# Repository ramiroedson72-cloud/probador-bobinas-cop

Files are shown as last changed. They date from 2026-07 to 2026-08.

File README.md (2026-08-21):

# Probador de bobinas COP — ESP32-C3 Super Mini

Generador de disparos PWM para probar bobinas de encendido (COP). Un potenciómetro
controla la frecuencia (10–200 Hz ≈ 300–6000 RPM en motor de 4 cilindros) y el
firmware mantiene un **dwell fijo de 3 ms** recalculando el duty. La pantalla
**OLED 128×64 I2C** muestra RPM, frecuencia, dwell y el logo SISU.

Diseñado por **Ramiro** · Logo SISU en la serigrafía inferior de la placa.

## Carcasa imprimible

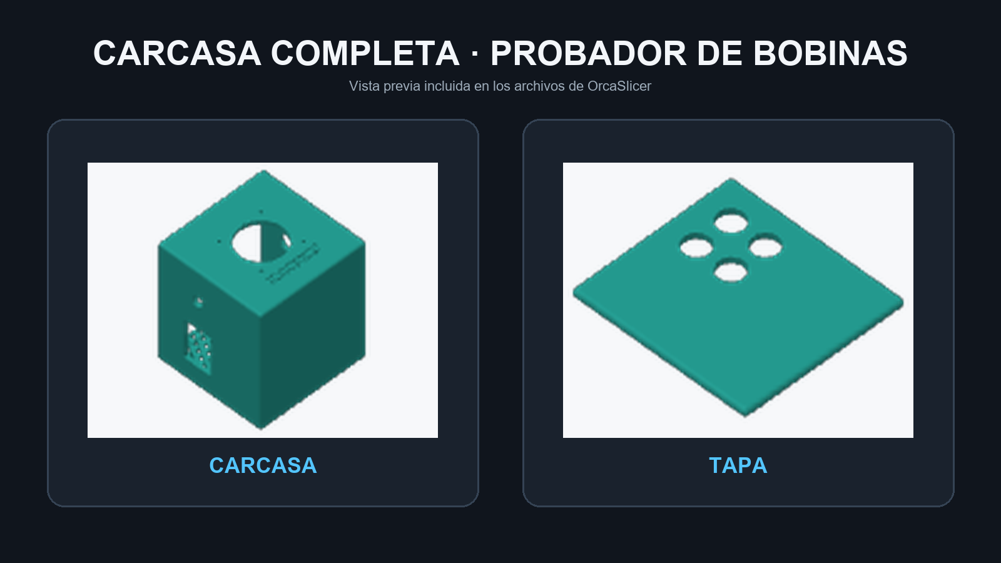
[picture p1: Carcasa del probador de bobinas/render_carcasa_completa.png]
Render de la carcasa completa y su tapa


Los archivos `carcasa.gcode` y `tapa carcasa.gcode` están listos para impresión
y fueron generados con OrcaSlicer.

## Estructura del repositorio

| Carpeta / archivo | Contenido |
|---|---|
| `Probador_Bobinas.ino` | Firmware para ESP32-C3 (Arduino) |
| `Probador_Bobinas_PCB/` | Proyecto KiCad 10 (esquemático + placa) |
| `Probador_Bobinas_PCB/PARA_FABRICAR/` | **Gerbers ZIP** — se sube tal cual a JLCPCB/PCBWay (2 capas, 1.6 mm, 1 oz) |
| `Probador_Bobinas_PCB/fabricacion/` | STEP 3D de la placa armada, esquemático PDF y BOM CSV |
| `PCB bobina Imprimir/` | PDFs 1:1 para **fabricación casera**: cobre para planchar (2), máscara UV (2), serigrafía (2) y STEP del LCD 20x4 para la carcasa |
| `Carcasa del probador de bobinas/` | G-code de la carcasa y la tapa, más su render conjunto |
| `libreria_kicad_SnapEDA/` | Librería KiCad autocontenida: símbolos, footprints y modelos 3D de todas las partes no estándar |

> Para abrir el proyecto KiCad en otra PC: registrar `libreria_kicad_SnapEDA` como
> librería "SnapEDA" (símbolos y footprints) en las tablas globales.

## La placa

- 61 × 74 × 1.6 mm, doble cara, componentes THT (pensada para soldar a mano)
- Etapa de potencia: **IGBT FGH60N60SFD** (600 V / 60 A, TO-247) con zener 15 V
  gate-emisor — reemplaza al IRLZ44N del prototipo (que avalanchaba a 55 V)
- Alimentación lógica: módulo **LM2596** 12 V → 5 V
- Clemas WAGO 236-402 (12 V y bobina), potenciómetro WH148 al borde (panel),
  header 1x4 para la pantalla OLED I2C
- Reglas de diseño: pista del colector con **2.5 mm de separación** (flyback
  ~400 V), potencia a 2 mm (10 A pulsados), señales a 0.8 mm (aptas para planchado)
- Plano de tierra cuadriculado en ambas caras; taladros M3 de esquina **H1/H2/H4
  con anillo a GND** para aterrizar la carcasa metálica (H3 solo mecánico)
- Rutas de refuerzo con alambre marcadas en la capa `Cmts.User` (retorno GND,
  colector 300 V y VCC de bobina) para la versión casera

## Cableado externo

| Conexión | Detalle |
|---|---|
| Clema J2 | Entrada 12 V (batería/fuente que aguante picos de 5–10 A) + fusible 5 A externo |
| Clema J1 | Primario de la bobina COP |
| Header J3 | OLED 128×64 I2C: 5V · GND · SDA (GPIO8) · SCL (GPIO9) |
| Cuerpo (rosca) de la bujía | GND de potencia — sin esto no hay chispa |

## Compilar y subir (Arduino IDE)

1. Instalar el core ESP32: Preferencias → URLs adicionales →
   `https://espressif.github.io/arduino-esp32/package_esp32_index.json`,
   luego Boards Manager → instalar "esp32 by Espressif Systems".
2. Instalar las librerías **Adafruit GFX** y **Adafruit SSD1306**.
3. Placa: **ESP32C3 Dev Module**, con **USB CDC On Boot: Enabled**.
4. Compilar y subir. Si no entra en modo de programación: mantener BOOT,
   pulsar RESET, soltar BOOT.

El sketch es compatible con el core ESP32 v2.x y v3.x (detecta la API de LEDC
automáticamente).

## Fabricación

**Profesional:** subir `PARA_FABRICAR/Probador_Bobinas_GERBERS.zip` a JLCPCB —
2 capas, 1.6 mm, cobre 1 oz, resto por defecto. (El PCBA no aplica: el ESP32
SuperMini y el módulo LM2596 son módulos de aftermarket que se sueldan a mano.)

**Casera (planchado + máscara UV):** PDFs en `PCB bobina Imprimir/`, impresora
láser a escala 100 % (el contorno debe medir 61 × 74 mm). Los archivos indican
en su nombre si van espejados o no. Las 7 vías se hacen con alambre pasante
soldado por ambos lados. Máscara UV: imprimir 2 acetatos por cara y encimarlos.

## Advertencias

- El primario genera picos de 300–400 V al cortar. El IGBT los soporta con
  margen, pero usar **disipador** en sesiones largas (hay espacio junto a Q1).
- No poner diodo flyback ni TVS en el primario: mata la chispa.
- Mantener los cables de alta tensión lejos del ESP32 (el EMI de la chispa
  puede resetearlo).
- Probar siempre con bujía o chispómetro conectado a la bobina.

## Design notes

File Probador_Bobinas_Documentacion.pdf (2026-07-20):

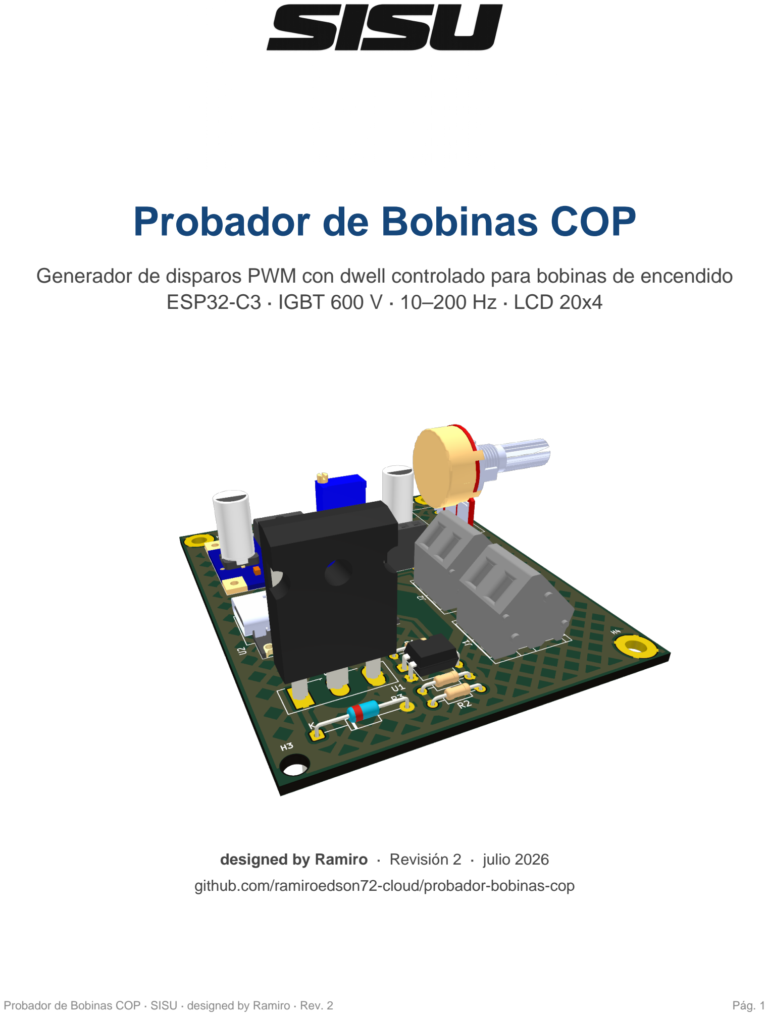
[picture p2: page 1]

Probador de Bobinas COP · SISU · designed by Ramiro · Rev. 2 | Pág. 1

# Probador de Bobinas COP

## Generador de disparos PWM con dwell controlado para bobinas de encendido ESP32-C3 · IGBT 600 V · 10–200 Hz · LCD 20x4

designed by Ramiro · Revisión 2 · julio 2026 github.com/ramiroedson72-cloud/probador-bobinas-cop

Probador de Bobinas COP · SISU · designed by Ramiro · Rev. 2 | Pág. 2

## Índice

1. Descripción general | 3
2. Especificaciones | 3
3. Firmware y funcionamiento | 4
4. La placa (PCB) | 5
5. Lista de materiales (BOM) | 7
6. Biblioteca de componentes | 7
7. Fabricación | 8
8. Puesta en marcha (primer arranque) | 8
9. Solución de problemas | 8
10. Conexión y seguridad | 10
11. Carcasa | 10
12. Historial del diseño | 10
13. Repositorio | 10
14. Código fuente comentado (Probador_Bobinas.ino) | 12

Anexo A: Esquemático completo — última página

Probador de Bobinas COP · SISU · designed by Ramiro · Rev. 2 | Pág. 3

## 1. Descripción general

El probador genera pulsos de disparo para bobinas de encendido tipo COP (Coil-On-Plug) simulando el trabajo real del motor: un potenciómetro ajusta la frecuencia de chispa entre 10 y 200 Hz (300–6000 RPM en un motor de 4 cilindros) y el firmware mantiene un dwell fijo de 3 ms recalculando el ciclo de trabajo del PWM en cada ajuste. El estado se muestra en una LCD 20x4 I2C (opcional, con autodetección) y por el monitor serial.
La cadena de disparo es: ESP32-C3 → optoacoplador PC817 → IGBT FGH60N60SFD → primario de la bobina. El optoacoplador aísla galvánicamente la lógica de 3.3 V del lado de potencia de 12 V, y el IGBT de 600 V absorbe con margen el flyback de 300–400 V que genera el primario en cada corte. Un zener de 15 V protege el gate y un módulo buck LM2596 genera los 5 V lógicos.

## 2. Especificaciones

Parámetro | Valor
Alimentación | 12 V DC (batería o fuente, picos de 5-10 A)
Frecuencia de disparo | 10 - 200 Hz (potenciómetro) = 300 - 6000 RPM en 4 cil.
Dwell | 3 ms fijos; sobre ~133 Hz lo limita el tope de duty del 40%
Corriente de primario | ~3 A con primario de 3.2 Ω (hasta ~10 A según bobina)
Flyback soportado | 300 - 400 V (IGBT de 600 V con margen)
Microcontrolador | ESP32-C3 Super Mini (USB-C)
Display | LCD 20x4 I2C (PCF8574) - opcional, autodetectado en 0x27/0x3F
Placa | 61 x 74 x 1.6 mm, 2 capas, THT
Altura máx. componentes | ~24 mm (IGBT TO-247)

Probador de Bobinas COP · SISU · designed by Ramiro · Rev. 2 | Pág. 4

## 3. Firmware y funcionamiento

El sketch (Probador_Bobinas.ino, Arduino) usa el periférico LEDC del ESP32-C3 a 14 bits de resolución, lo que permite generar con precisión todo el rango de 10 a 200 Hz. El lazo principal promedia 16 lecturas del potenciómetro, mapea el valor a frecuencia y solo reconfigura el PWM cuando el cambio es real (≥2 Hz) para evitar glitches en el tren de pulsos. El duty se recalcula como dwell x frecuencia, con tope de seguridad del 40% — por eso a más de ~133 Hz el dwell efectivo baja gradualmente de 3 ms (protege bobina e IGBT a altas RPM).

## 3.1 Asignación de pines

Pin ESP32-C3 | Función
GPIO3 (ADC) | Cursor del potenciómetro (extremos a 3V3 y GND)
GPIO4 | Salida PWM → R1 150 Ω → LED del PC817
GPIO8 | SDA de la LCD 20x4 I2C
GPIO9 | SCL de la LCD 20x4 I2C
5V | Alimentación desde el LM2596 (vía red de 5 V de la placa)

## 3.2 Interfaz

La LCD muestra frecuencia real del LEDC, RPM equivalentes (4 cilindros), dwell y duty. Si no hay LCD conectada el probador funciona igual y reporta por serial a 115200 baudios una línea cada 200 ms con el ADC crudo del potenciómetro (útil para diagnosticarlo: debe recorrer ~0 a ~4095), la frecuencia objetivo, la frecuencia real y el duty aplicado.

## 3.3 Compilación

Core ESP32 de Arduino v2.x o v3.x (el sketch detecta la API de LEDC automáticamente). Librería LiquidCrystal I2C (Frank de Brabander). Placa: ESP32C3 Dev Module con USB CDC On Boot: Enabled. Si no entra a programación: mantener BOOT, pulsar RESET, soltar BOOT.

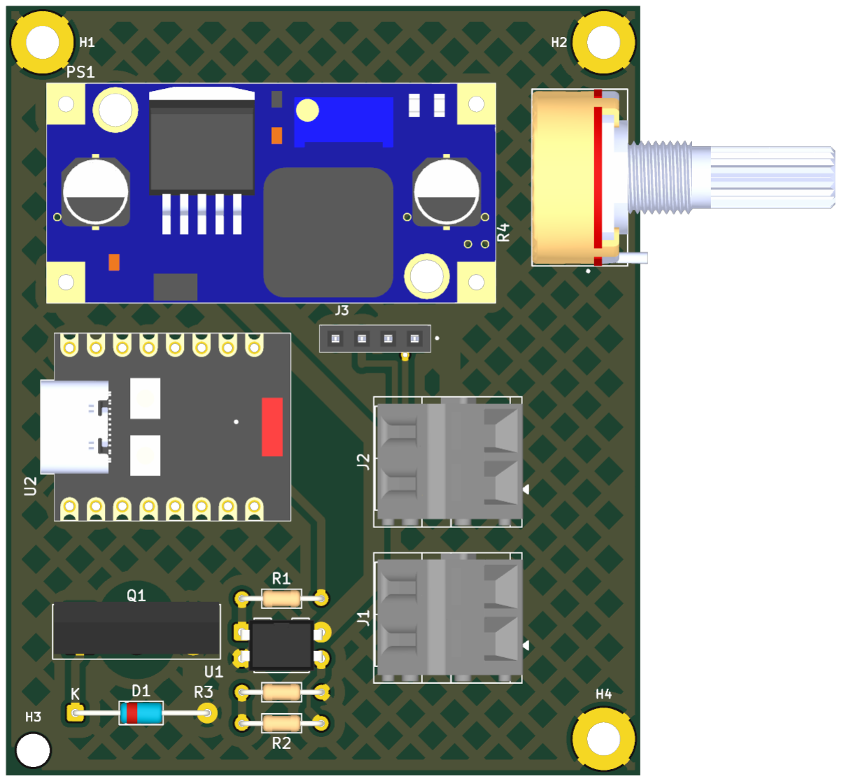
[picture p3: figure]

Probador de Bobinas COP · SISU · designed by Ramiro · Rev. 2 | Pág. 5

## 4. La placa (PCB)

Diseñada en KiCad 10, 100% THT para armado a mano. Enrutado con Freerouting más retoques manuales bajo reglas por clases de red: la pista del colector del IGBT (flyback de ~400 V) exige 2.5 mm de separación; la potencia va a 2 mm; las señales a 0.8 mm (aptas para tóner). Ambas caras llevan plano de tierra cuadriculado (1 mm / hueco 2 mm a 45°) que drena las señales parásitas, y los taladros M3 de H1, H2 y H4 tienen anillo a GND para aterrizar la carcasa metálica con los propios tornillos (H3 es solo mecánico). La cara inferior lleva el logo SISU y la leyenda designed by Ramiro. Verificación DRC final: cero violaciones.

Cara superior: LM2596 (PS1), potenciómetro al borde, ESP32-C3 (U2), clemas WAGO (J1/J2), IGBT (Q1) y etapa de disparo.

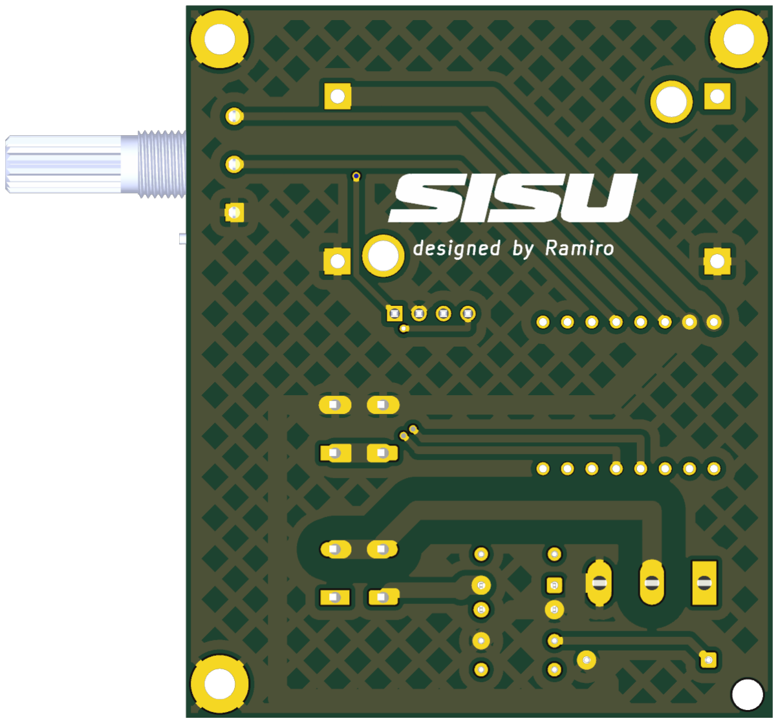
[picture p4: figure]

Probador de Bobinas COP · SISU · designed by Ramiro · Rev. 2 | Pág. 6

Cara inferior: pistas, malla GND, logo SISU. La pista ancha diagonal es el colector (alta tensión).

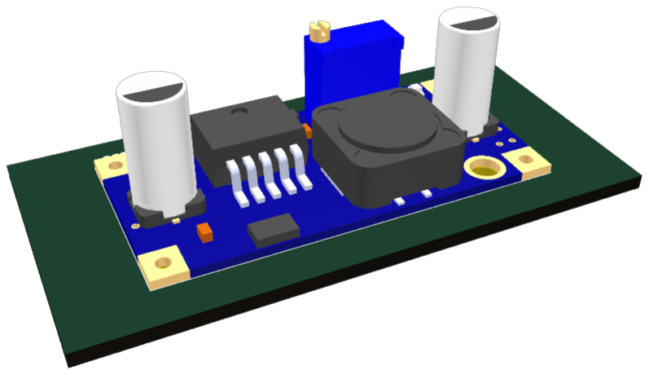
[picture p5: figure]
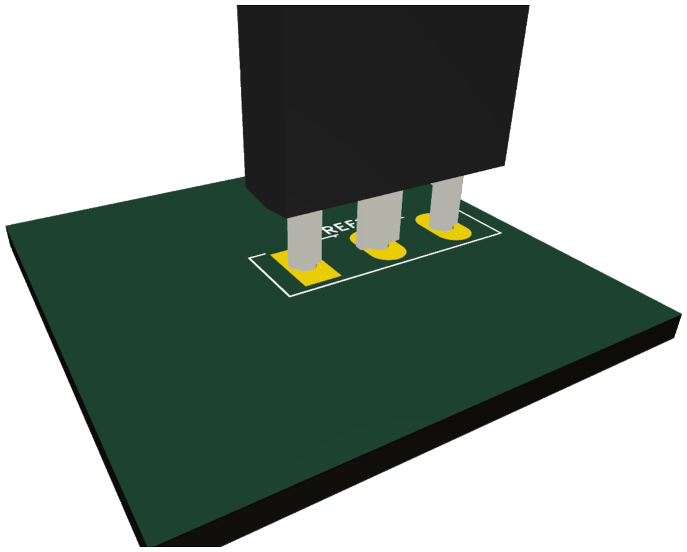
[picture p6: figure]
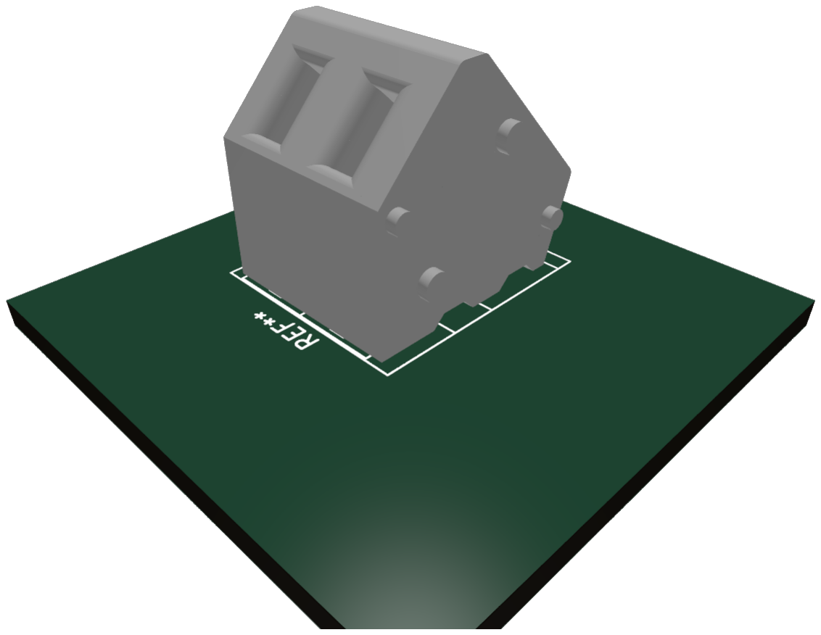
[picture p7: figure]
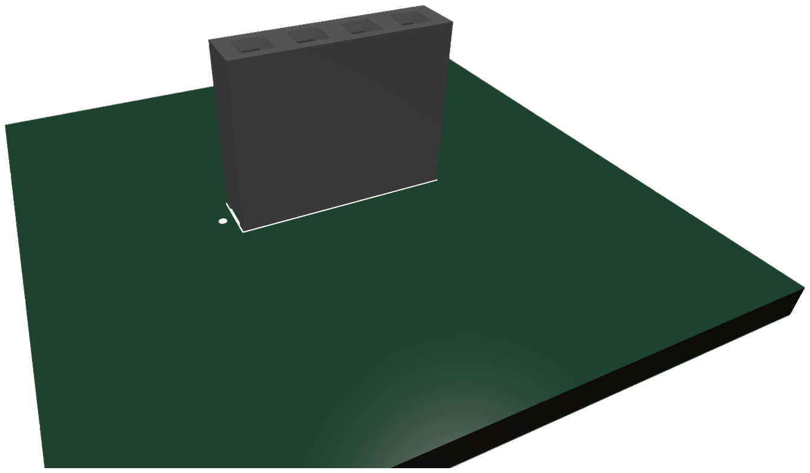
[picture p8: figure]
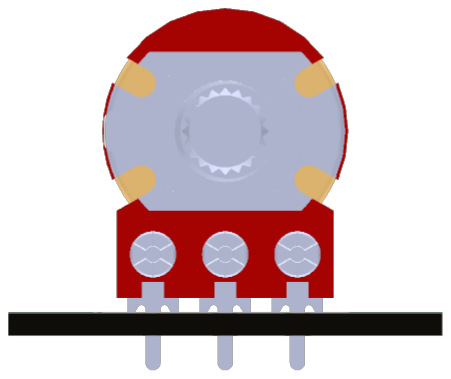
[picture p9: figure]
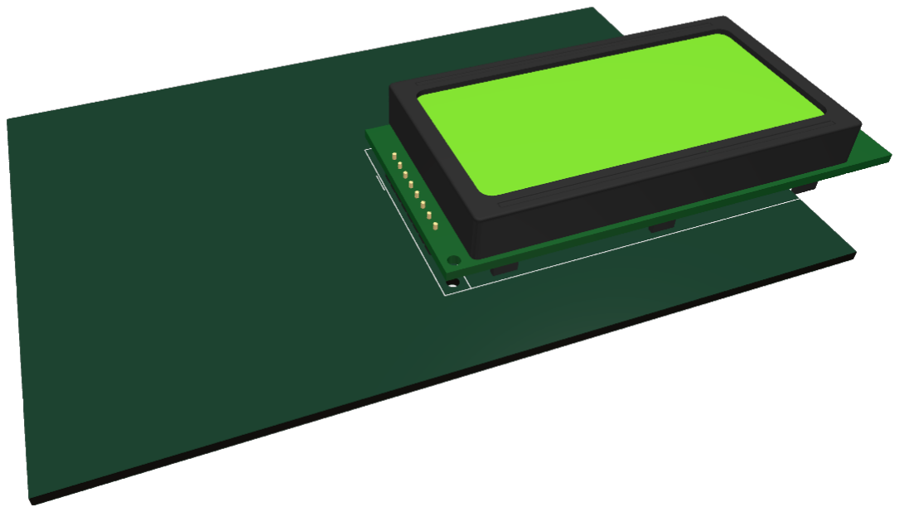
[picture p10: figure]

Probador de Bobinas COP · SISU · designed by Ramiro · Rev. 2 | Pág. 7

## 5. Lista de materiales (BOM)

Ref. | Componente | Cant.
D1 | D_Zener 15V | 1
J1,J2 | WAGO_236-402 | 2
J3 | PPTC041LFBN-RC | 1
PS1 | MC00100 | 1
Q1 | FGH60N60SFD | 1
R1 | R_150 | 1
R2 | R_100 | 1
R3 | R_560 | 1
R4 | WH148-1A-2-18T-L20 | 1
U1 | PC817 | 1
U2 | ESP32-C3_SUPERMINI_TH | 1
- | LCD 20x4 I2C (PCF8574) - externo vía J3 | 1
- | Fusible rápido 5 A con portafusible (externo) | 1
H1-H4 | Tornillos M3 (latón o acero) - H1/H2/H4 aterrizan la carcasa | 4

Valores: R1 150 Ω (serie del LED del opto), R2 100 Ω (serie de gate), R3 560 Ω (pull-down de gate), R4 potenciómetro WH148 10 kΩ, D1 zener 15 V gate-emisor.

## 6. Biblioteca de componentes

Las partes no estándar se integraron a una librería KiCad propia (símbolo + footprint + modelo 3D verificado por render). La librería viaja con el repositorio (libreria_kicad_SnapEDA) para que el proyecto abra completo en cualquier PC.

Módulo LM2596 | IGBT TO-247 | Clema WAGO 236-402
Header hembra 1x4 | Potenciómetro WH148 | LCD 20x4 (para carcasa)

Probador de Bobinas COP · SISU · designed by Ramiro · Rev. 2 | Pág. 8

## 7. Fabricación

## 7.1 Profesional (JLCPCB / PCBWay)

Subir PARA_FABRICAR/Probador_Bobinas_GERBERS.zip tal cual. Opciones: 2 capas, 1.6 mm, cobre 1 oz, resto por defecto. El PCBA no aplica: el ESP32 SuperMini y el LM2596 son módulos de aftermarket que se sueldan a mano.

## 7.2 Casera (transferencia de tóner + máscara UV)

PDFs a escala 1:1 en PCB bobina Imprimir (láser al 100%; el contorno debe medir 61 x 74 mm):

Archivo | Uso
planchar_COBRE_ABAJO_no_espejar | Cobre inferior - se imprime tal cual
planchar_COBRE_ARRIBA_ya_espejado | Cobre superior - ya viene espejado
mascaraUV_ABAJO / ARRIBA | Acetatos de máscara UV (pads en negro; 2 copias por cara encimadas)
serigrafia_ARRIBA / ABAJO | Serigrafía de componentes (arriba) y logo (abajo)

Las 7 vías se hacen con alambre pasante soldado por ambos lados. Las tres rutas de alta corriente están marcadas con línea punteada en la capa Cmts.User (retorno GND, colector 300 V y VCC de bobina): en la versión casera se refuerzan estañando un alambre de cobre desnudo (~18-20 AWG) sobre la pista. En la placa de fábrica no es necesario.

## 8. Puesta en marcha (primer arranque)

Seguir el orden: cada paso protege al siguiente.
1. Inspección visual y de continuidad: revisar con multímetro que no haya puentes entre pistas vecinas, en especial el corredor entre J3 y la clema J2 (pistas de 0.6 mm) si la placa es casera.
2. SIN el ESP32 insertado y sin bobina: conectar 12 V a J2 (con fusible de 5 A) y ajustar el trimmer del LM2596 hasta medir 5.0 V entre el pin 1 de J3 y GND. Este paso evita quemar el ESP32 si el módulo viene ajustado alto de fábrica.
3. Cortar alimentación, insertar el ESP32 (USB hacia el borde izquierdo) y reconectar. Abrir el monitor serial (115200): girar el potenciómetro y verificar que el ADC recorra ~0 a ~4095 y la frecuencia real siga a la objetivo.
4. Conectar la bobina COP en J1 y una bujía en su torre, con el cuerpo de la bujía firmemente a GND de potencia (sin este retorno no hay chispa y el flyback sube de más).
5. Arrancar en 10 Hz (potenciómetro al mínimo) y subir gradualmente. La chispa debe ser azul y constante en todo el rango.

## 9. Solución de problemas

Síntoma | Causa probable | Qué hacer
No hay chispa | Bujía sin retorno a GND / bobina mal conectada / fusible abierto | Verificar cuerpo de bujía a GND de potencia, continuidad de J1 y fusible
Chispa débil o intermitente | Dwell insuficiente a alta frecuencia / 12 V caídos | Probar a baja frecuencia; alimentar con batería o fuente de 5-10 A
El ESP32 se reinicia al chispear | EMI del secundario / cables de AT junto a la lógica | Alejar bobina y cables de bujía de la placa; verificar malla GND y carcasa aterrizada
LCD no enciende o basura | Dirección I2C distinta / contraste / cables SDA-SCL cruzados | El firmware busca 0x27 y 0x3F; ajustar trimmer del backpack; revisar J3

Probador de Bobinas COP · SISU · designed by Ramiro · Rev. 2 | Pág. 9
Síntoma | Causa probable | Qué hacer
IGBT muy caliente | Sesión larga a alta frecuencia sin disipador | Atornillar disipador al TO-247 (hay espacio junto a Q1); pausar entre pruebas
ADC no llega a 0 o a 4095 | Potenciómetro mal cableado o dañado | Ver monitor serial; revisar soldaduras de R4 (extremos a 3V3/GND, cursor a GPIO3)

Probador de Bobinas COP · SISU · designed by Ramiro · Rev. 2 | Pág. 10

## 10. Conexión y seguridad

Punto | Conexión
Clema J2 | Entrada 12 V (con fusible externo de 5 A rápido)
Clema J1 | Primario de la bobina COP
Header J3 | LCD 20x4 I2C: 5V - GND - SDA (GPIO8) - SCL (GPIO9)
Bujía | El cuerpo (rosca) va a GND de potencia
Potenciómetro | Frecuencia de disparo (10-200 Hz)
USB-C del ESP32 | Reprogramación y monitor serial

Seguridad: el secundario de una bobina COP supera los 30 kV — nunca tocar la bujía ni su torre con el equipo energizado. Probar siempre con bujía o chispómetro conectado. No agregar diodo flyback ni TVS al primario (mata la chispa). Personas con marcapasos deben mantener distancia. Trabajar en área ventilada y sin combustibles cerca.

## 11. Carcasa

Placa de 61 x 74 mm; taladros M3 en H1 (93.5, 41.5), H2 (147.5, 41.5), H3 (92.6, 109.6) y H4 (147.5, 108.5) en coordenadas del proyecto. Altura interior mínima 35 mm. El eje del potenciómetro sale ~20 mm por el borde derecho (atraviesa el panel); las clemas miran al mismo lado; el USB-C queda a la izquierda (prever ranura). Si la carcasa es metálica, los tornillos de H1/H2/H4 la aterrizan al plano GND (usar rondana dentada en al menos uno). El LCD 20x4 (98 x 60 mm, ventana 76 x 25 mm, taladros 93 x 55 mm) requiere ~25 mm de profundidad con su backpack I2C. Modelos 3D en el repositorio: Probador_Bobinas_3D.step y LCD_20x4_NHD-0420H1Z.step.

## 12. Historial del diseño

Versión | Descripción | Estado
v1 - protoboard | IRLZ44N (MOSFET 55 V): el flyback se disipaba en avalancha dentro del transistor. A alta frecuencia la disipación lo quemó; se limitó el firmware a 60 Hz y dwell 2 ms. | Superada
v2 - PCB (esta) | IGBT FGH60N60SFD de 600 V: absorbe el flyback con margen. Rango completo de 10-200 Hz y dwell de 3 ms restaurados. PCB con reglas de alta tensión, malla GND y carcasa aterrizable. | Actual

## 13. Repositorio

Proyecto completo (público): github.com/ramiroedson72-cloud/probador-bobinas-cop — firmware Arduino, proyecto KiCad, gerbers, PDFs de fabricación casera, librería de componentes autocontenida,
STEP 3D, esquemático PDF, BOM y esta documentación.

Escanea para abrir el repositorio en GitHub

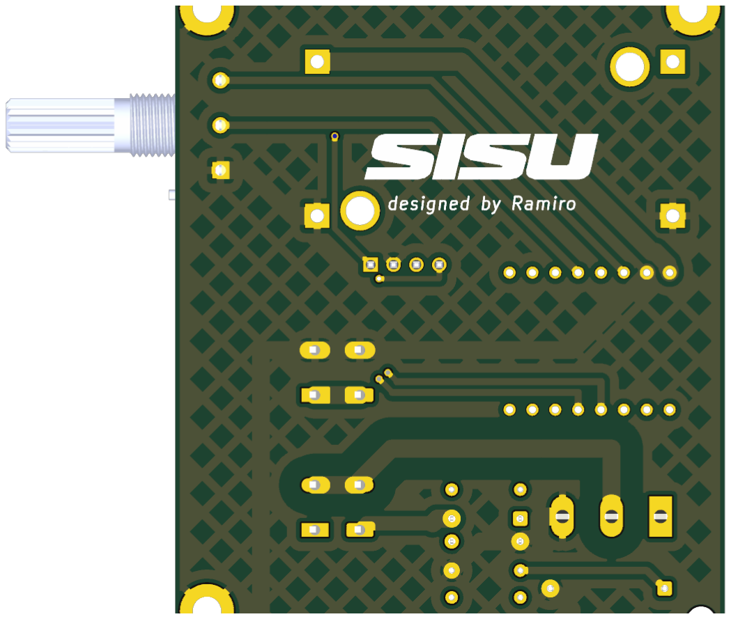
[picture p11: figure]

Probador de Bobinas COP · SISU · designed by Ramiro · Rev. 2 | Pág. 11

Detalle de la cara inferior: logo SISU y designed by Ramiro en serigrafía.

Probador de Bobinas COP · SISU · designed by Ramiro · Rev. 2 | Pág. 12

## 14. Código fuente comentado (Probador_Bobinas.ino)

El firmware cabe en un solo sketch de ~165 líneas. Su estructura:

Bloque | Qué hace
Configuración | Pines (pot GPIO3, PWM GPIO4, I2C 8/9) y constantes: FREQ 10-200 Hz, DWELL 3 ms, tope de duty 40%, LEDC a 14 bits (necesarios para que las frecuencias bajas no fallen en silencio).
detectarLcd() | Busca el backpack PCF8574 en 0x27 y 0x3F; si no aparece, el equipo opera solo con el monitor serial.
aplicarPwm() / freqReal() | Capa de compatibilidad entre el core ESP32 v2.x (API de canales) y v3.x (API por pin), con verificación de que el LEDC aceptó la frecuencia.
dutyParaDwell() | Convierte el dwell fijo en duty proporcional a la frecuencia (duty = dwell x f), recortado al 40% de seguridad.
setup() | Serial, I2C + LCD, ADC a 12 bits y arranque del PWM en 10 Hz; si el LEDC falla, se detiene con mensaje de error.
loop() | Promedia 16 lecturas del pot, mapea a frecuencia y solo reconfigura el LEDC con cambios reales (>=2 Hz) para no glitchear el tren de pulsos; refresca LCD/serial cada 200 ms con frecuencia real, RPM, dwell y duty.

## 14.1 Listado completo

/*
* Probador de bobinas de encendido COP
* ESP32-C3 Super Mini + PC817 + IGBT FGH60N60SFD (PCB v2)
*
* El potenciometro controla la frecuencia de disparo (10-200 Hz). * El dwell (tiempo de carga de la bobina) se mantiene fijo en 3 ms * recalculando el duty en cada cambio, con tope de seguridad del 40% * (a mas de ~133 Hz el tope reduce el dwell gradualmente).
*
* Conexiones (segun PCB v2):
* | GPIO3 <- cursor del potenciometro WH148 (extremos a 3V3 y GND)
* | GPIO4 -> R1 150R -> pin 1 PC817 (pin 2 a GND logico)
* | GPIO8 -> SDA de la LCD 20x4 (backpack PCF8574, alimentada a 5V)
* | GPIO9 -> SCL de la LCD
*
* Compatible con el core ESP32 de Arduino v2.x y v3.x.
*/

#include <Wire.h>

#include <LiquidCrystal_I2C.h>

// ---------- Configuracion ----------
const int | PIN_POT | = 3; | // entrada ADC del potenciometro
const int | PIN_PWM | = 4; | // salida hacia el opto/MOSFET
const int | PIN_SDA | = 8;
const int | PIN_SCL | = 9;
const int | FREQ_MIN = 10; | // Hz (= 300 RPM en motor 4 cil.)
// Con el IGBT FGH60N60SFD (600 V) el flyback de la bobina ya no se disipa // en avalancha: el rango completo es seguro. (Con el IRLZ44N del prototipo // v1 habia que limitar a 60 Hz porque el MOSFET clampeaba a 55 V y ardia.)
const int | FREQ_MAX = 200; | // Hz (= 6000 RPM en motor 4 cil.)
// 3 ms: dwell tipico de bobina COP (primario 3.2 ohms -> ~3 A de pico). const float DWELL_MS = 3.0; // tiempo de carga de la bobina
const float DUTY_MAX = 0.40; // tope de seguridad de duty (40%)

// 14 bits: con el reloj de 80 MHz el LEDC acepta de 4.8 Hz a 4.8 kHz, // asi todo el rango 10-200 Hz es valido. Con 12 bits el minimo era // ~19 Hz y las frecuencias bajas fallaban en silencio.
const int RES_BITS = 14;
const uint32_t DUTY_FULL = (1UL << RES_BITS) - 1;

#if !defined(ESP_ARDUINO_VERSION_MAJOR) || ESP_ARDUINO_VERSION_MAJOR < 3

#define CORE_V2 | // API antigua de LEDC (canales)

const int PWM_CHANNEL = 0;
#endif

LiquidCrystal_I2C *lcd = nullptr;
bool hayLcd = false;
int freqActual = 0; | // frecuencia aplicada al LEDC
uint32_t lastLcd = 0;

// Busca la LCD en las dos direcciones tipicas del backpack PCF8574

Probador de Bobinas COP · SISU · designed by Ramiro · Rev. 2 | Pág. 13

uint8_t detectarLcd() {
const uint8_t dirs[] = {0x27, 0x3F};
for (uint8_t d : dirs) {
Wire.beginTransmission(d);

if (Wire.endTransmission() == 0) return d; }
return 0;
}

// Devuelve la frecuencia que el LEDC esta generando de verdad uint32_t freqReal() {
#ifdef CORE_V2

return ledcReadFreq(PWM_CHANNEL);
#else

return ledcReadFreq(PIN_PWM);
#endif

}

// Reconfigura el LEDC. Devuelve false si el driver rechazo la frecuencia. bool aplicarPwm(int freq, uint32_t duty) {
#ifdef CORE_V2

bool ok = ledcChangeFrequency(PWM_CHANNEL, freq, RES_BITS) != 0; ledcWrite(PWM_CHANNEL, duty);
#else

bool ok = ledcChangeFrequency(PIN_PWM, freq, RES_BITS) != 0; ledcWrite(PIN_PWM, duty);
#endif

return ok;
}

uint32_t dutyParaDwell(int freq) {
float dutyFrac = DWELL_MS * freq / 1000.0f; if (dutyFrac > DUTY_MAX) dutyFrac = DUTY_MAX; return dutyFrac * DUTY_FULL;
}

void setup() {
Serial.begin(115200);

Wire.begin(PIN_SDA, PIN_SCL);
uint8_t dir = detectarLcd();
if (dir != 0) {
lcd = new LiquidCrystal_I2C(dir, 20, 4); lcd->init();
lcd->backlight();
lcd->setCursor(0, 0);
lcd->print("Probador de bobinas");
hayLcd = true;
Serial.printf("LCD encontrada en 0x%02X\n", dir);
} else {
Serial.println("LCD no detectada, sigo solo con Serial"); }

analogReadResolution(12);

#ifdef CORE_V2

ledcSetup(PWM_CHANNEL, FREQ_MIN, RES_BITS); ledcAttachPin(PIN_PWM, PWM_CHANNEL);
bool pwmOk = true;
#else

bool pwmOk = ledcAttach(PIN_PWM, FREQ_MIN, RES_BITS);
#endif

if (!pwmOk) {
Serial.println("ERROR: fallo la configuracion del PWM (LEDC)");
if (hayLcd) { lcd->setCursor(0, 1); lcd->print("ERROR config PWM!"); } while (true) delay(1000); // no tiene caso seguir
}

freqActual = FREQ_MIN;
aplicarPwm(FREQ_MIN, dutyParaDwell(FREQ_MIN));
}

void loop() {
// Promedio de 16 lecturas para estabilizar el pot
long suma = 0;
for (int i = 0; i < 16; i++) suma += analogRead(PIN_POT); int adc = suma / 16;

int freq = map(adc, 0, 4095, FREQ_MIN, FREQ_MAX);

// Solo reconfigurar el LEDC cuando el cambio es real (>= 2 Hz). // Reconfigurar en cada vuelta del loop reinicia el temporizador // antes de completar un periodo y el PWM sale glitcheado.
if (abs(freq - freqActual) >= 2) {
freqActual = freq;
if (!aplicarPwm(freqActual, dutyParaDwell(freqActual))) { Serial.printf("ERROR: LEDC rechazo %d Hz\n", freqActual); }
}

// Refresco de pantalla y serial cada 200 ms
if (millis() - lastLcd >= 200) {

Probador de Bobinas COP · SISU · designed by Ramiro · Rev. 2 | Pág. 14

lastLcd = millis();
int rpm = freqActual * 30; // motor 4 tiempos, 4 cilindros
int dutyPct = int(100.0f * dutyParaDwell(freqActual) / DUTY_FULL);

if (hayLcd) {
char linea[21];
snprintf(linea, sizeof(linea), "Frec: %3d Hz | ", (int)freqReal());
lcd->setCursor(0, 1); lcd->print(linea);
snprintf(linea, sizeof(linea), "RPM (4cil): %5d ", rpm); lcd->setCursor(0, 2); lcd->print(linea);
snprintf(linea, sizeof(linea), "Dwell:%.1fms D:%2d%% ", DWELL_MS, dutyPct); lcd->setCursor(0, 3); lcd->print(linea);
}
// adc crudo para diagnosticar el pot: debe ir de ~0 a ~4095 al girarlo Serial.printf("adc=%4d f_obj=%3d Hz f_real=%3u Hz duty=%d%%\n", adc, freqActual, freqReal(), dutyPct); }
}

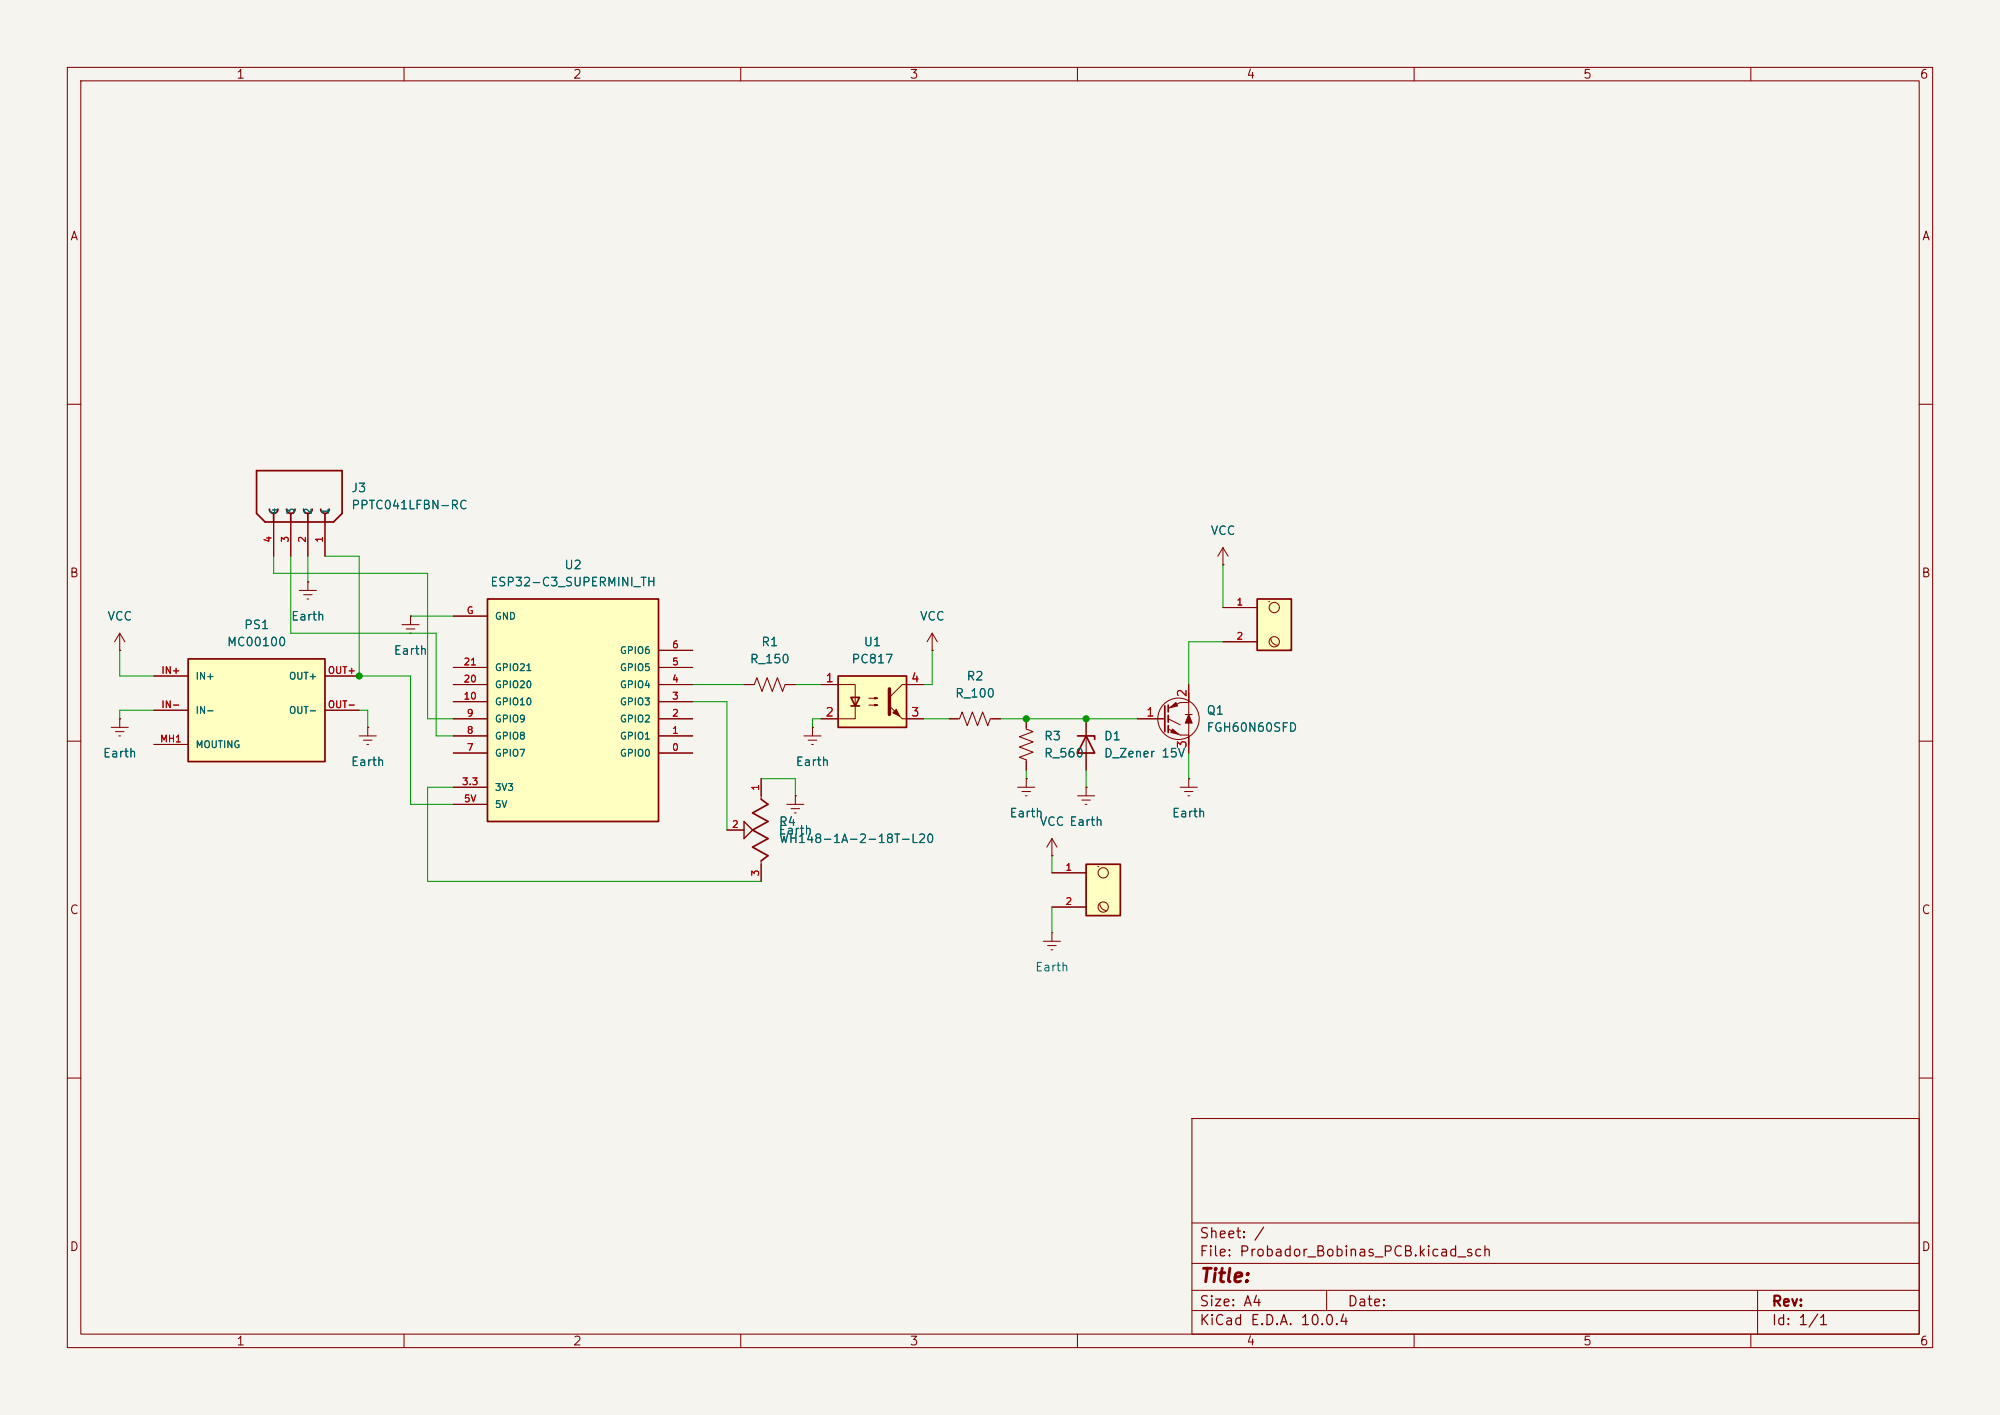
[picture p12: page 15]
D Date:; KiCad E.D.A. 10.0.4; Size: A4; Rev:; Title:; File: Probador_Bobinas_PCB.kicad_sch; Sheet: /; GPIO0; 0 GPIO1; 1 GPIO2; 2 GPIO3; GPIO4; 4 GPIO5; GPIO6; 6 GPIO7 7; GPIO8 8; GPIO9 9; GPIO10 10; GPIO20 20; GPIO21 21; GND G; ESP32-C3_SUPERMINI_TH; 4 J3PPTC041LFBN-RC; Earth; VCC; FGH60N60SFD; Earth R3R_560; Earth R2 R_100; MOUTING MH1; OUT+ OUT+; OUT- OUT- PS1 MC00100; D1D_Zener 15V; Earth PS1 MC00100; OUT- OUT-; J3 1PPTC041LFBN-RC; 2 Earth; VCC Q1

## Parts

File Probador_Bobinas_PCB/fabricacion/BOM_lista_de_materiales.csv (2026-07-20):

Referencia | Valor | Footprint | Cantidad
D1 | D_Zener 15V | Diode_THT:D_DO-35_SOD27_P12.70mm_Horizontal | 1
J1,J2 | WAGO_236-402 | SnapEDA:TerminalBlock_WAGO_236-402_1x02_P5.00mm_45Degree | 2
J3 | PPTC041LFBN-RC | SnapEDA:SULLINS_PPTC041LFBN-RC | 1
PS1 | MC00100 | SnapEDA:CONV_MC00100 | 1
Q1 | FGH60N60SFD | SnapEDA:TO-247-3_Vertical | 1
R1 | R_150 | Resistor_THT:R_Axial_DIN0204_L3.6mm_D1.6mm_P7.62mm_Horizontal | 1
R2 | R_100 | Resistor_THT:R_Axial_DIN0204_L3.6mm_D1.6mm_P7.62mm_Horizontal | 1
R3 | R_560 | Resistor_THT:R_Axial_DIN0204_L3.6mm_D1.6mm_P7.62mm_Horizontal | 1
R4 | WH148-1A-2-18T-L20 | SnapEDA:TRIM_WH148-1A-2-18T-L20 | 1
U1 | PC817 | Package_DIP:DIP-4_W7.62mm | 1
U2 | ESP32-C3_SUPERMINI_TH | SnapEDA:MODULE_ESP32-C3_SUPERMINI_TH | 1

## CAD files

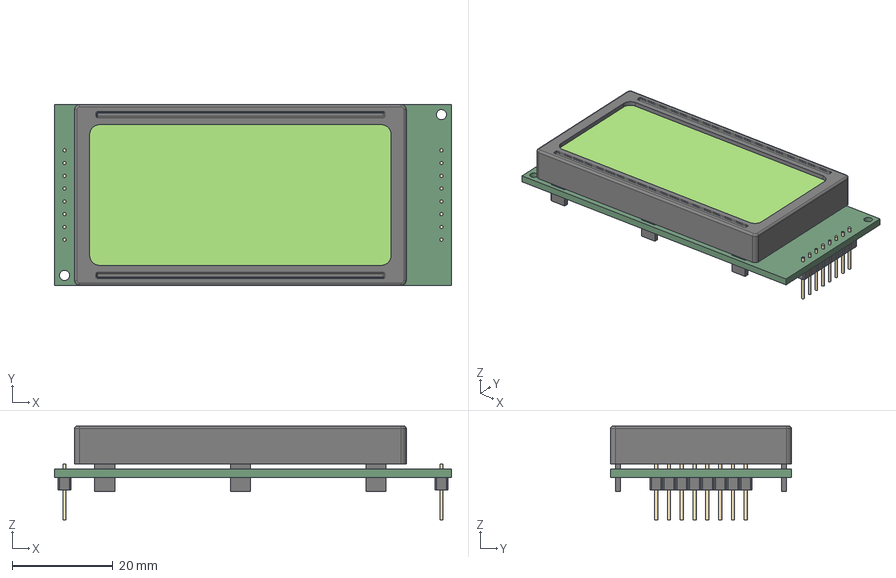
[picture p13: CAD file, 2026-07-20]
PCB bobina Imprimir/LCD_20x4_NHD-0420H1Z.step
79.0 x 36.0 x 18.7 mm

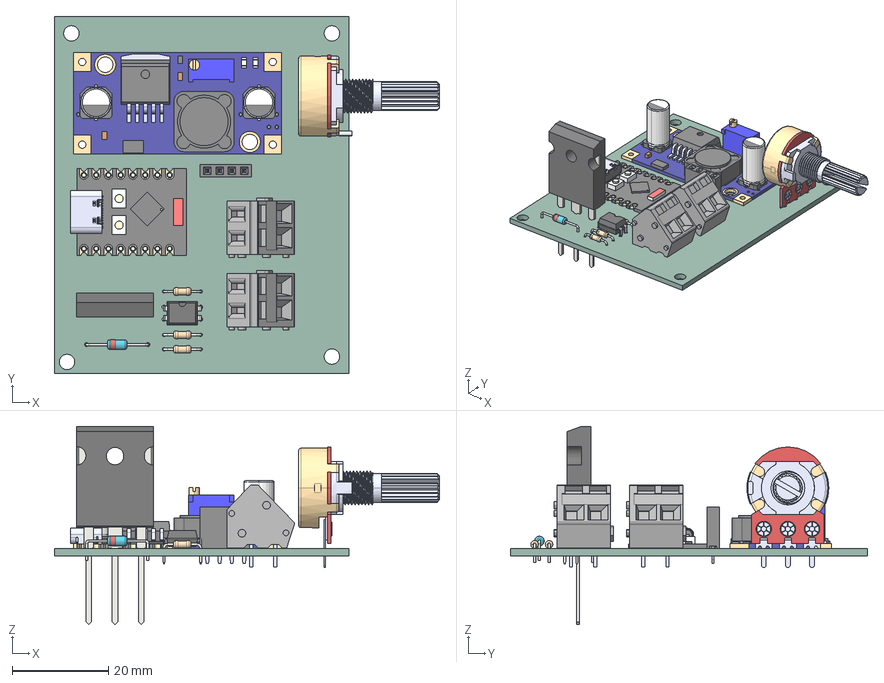
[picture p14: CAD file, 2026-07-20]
Probador_Bobinas_PCB/fabricacion/Probador_Bobinas_3D.step
79.8 x 74.0 x 41.1 mm
MC00100
3296W-1-104
DR125-331-R
LM2596DSADJG
EEE1HA470XAP x 2
R_Axial_DIN0204_L36mm_D16mm_P762mm_Horizontal x 3
Board c3mini
USB C
components (other)^ESP32-C3 SuperMini
PPTC041LFBN-RC
DIP-4_W7.62mm
WH148-1A-2
D_DO-35_SOD27_P12.70mm_Horizontal
TO-247-3_Vertical
Probador_Bobinas_PCB_PCB

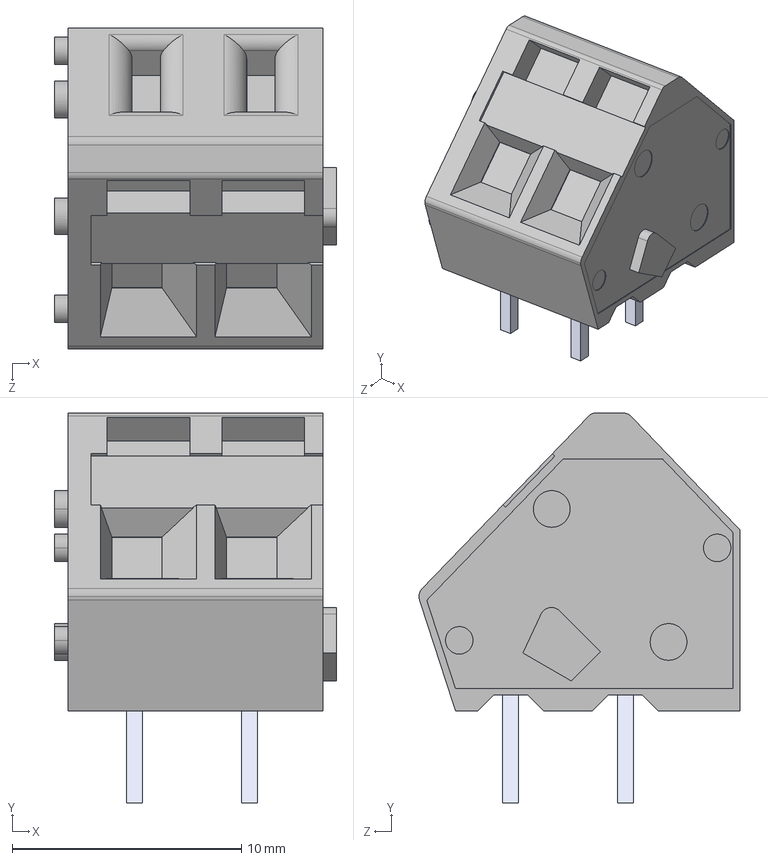
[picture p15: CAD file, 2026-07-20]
libreria_kicad_SnapEDA/3dmodels/WAGO_236-402.step
12.3 x 17.0 x 14.0 mm

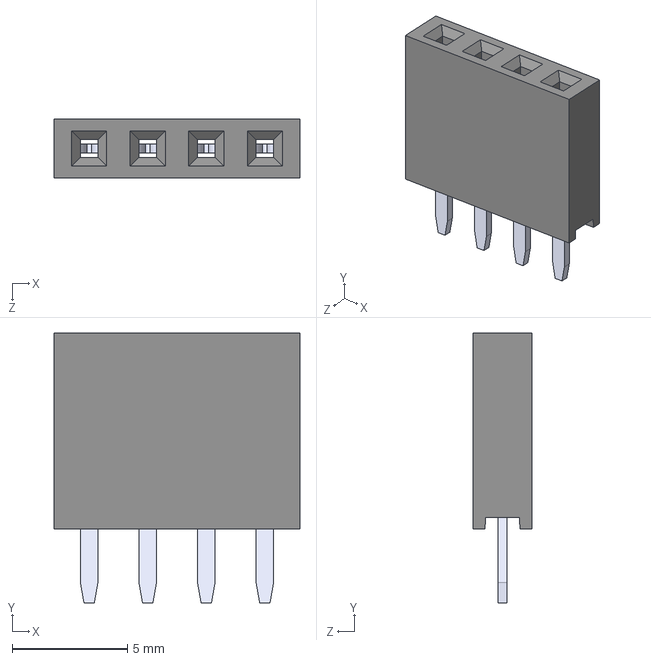
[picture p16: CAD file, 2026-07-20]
libreria_kicad_SnapEDA/3dmodels/PPTC041LFBN-RC.step
10.7 x 11.7 x 2.54 mm

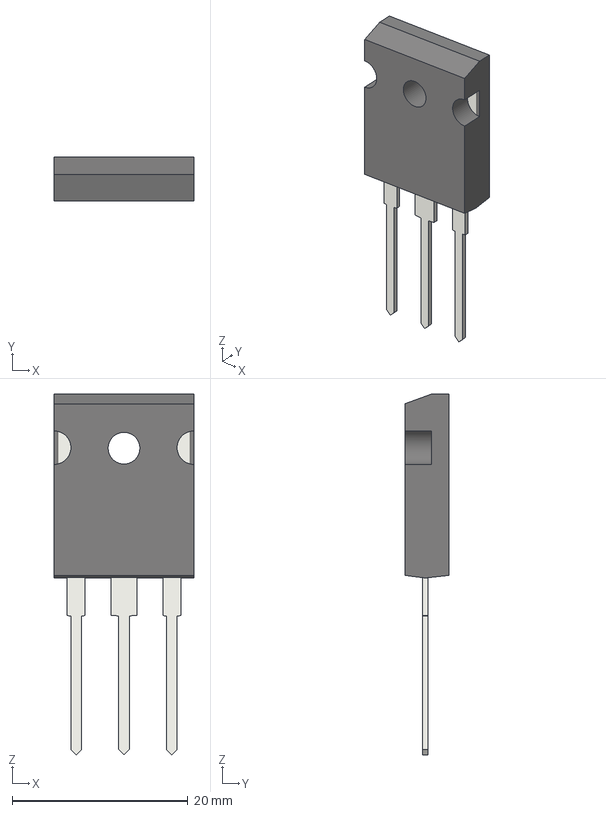
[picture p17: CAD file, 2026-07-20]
libreria_kicad_SnapEDA/3dmodels/TO-247-3_Vertical.step
15.9 x 5.03 x 41.1 mm

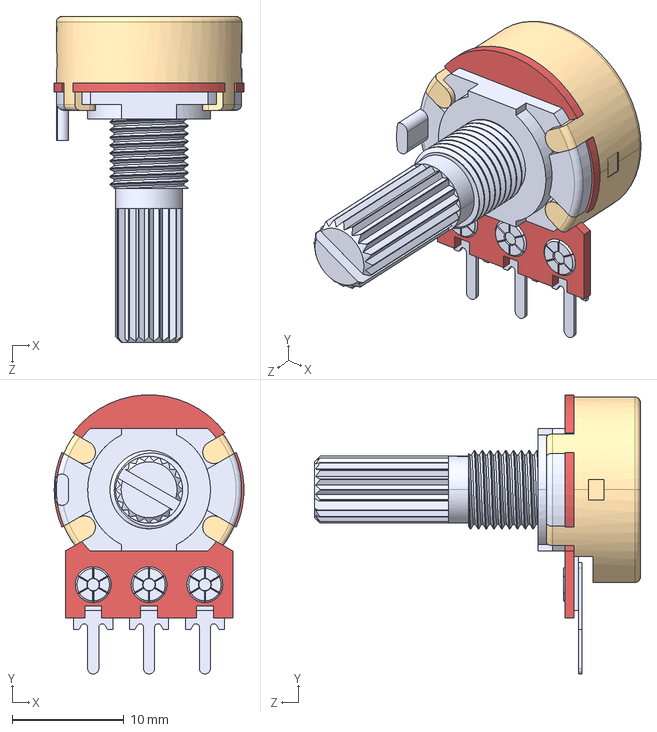
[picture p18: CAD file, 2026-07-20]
libreria_kicad_SnapEDA/3dmodels/WH148-1A-2-18T-L20.step
17.0 x 25.0 x 29.2 mm

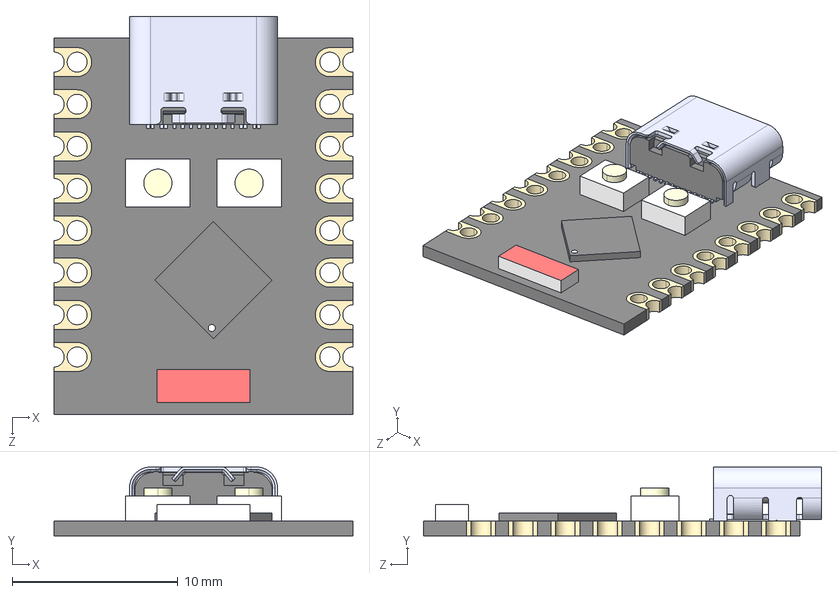
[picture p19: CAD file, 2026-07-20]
libreria_kicad_SnapEDA/3dmodels/ESP32-C3_SUPERMINI_TH.step
18.0 x 4.16 x 24.0 mm
Board c3mini
USB C
components (other)^ESP32-C3 SuperMini

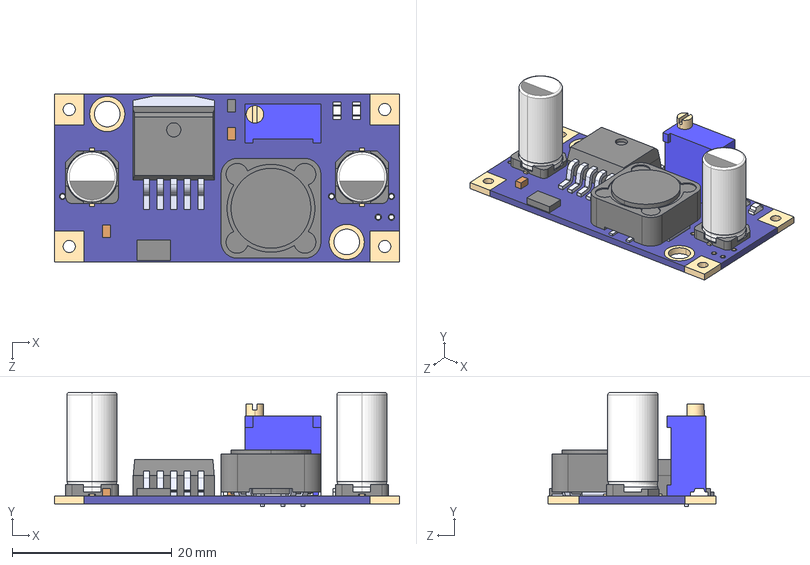
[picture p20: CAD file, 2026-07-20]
libreria_kicad_SnapEDA/3dmodels/MC00100.step
43.2 x 14.3 x 21.1 mm
MC00100
3296W-1-104
DR125-331-R
LM2596DSADJG
EEE1HA470XAP x 2

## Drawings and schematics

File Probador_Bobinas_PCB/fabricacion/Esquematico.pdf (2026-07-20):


Size: A4 | Rev:
KiCad E.D.A. 10.0.4 | Id: 1/1

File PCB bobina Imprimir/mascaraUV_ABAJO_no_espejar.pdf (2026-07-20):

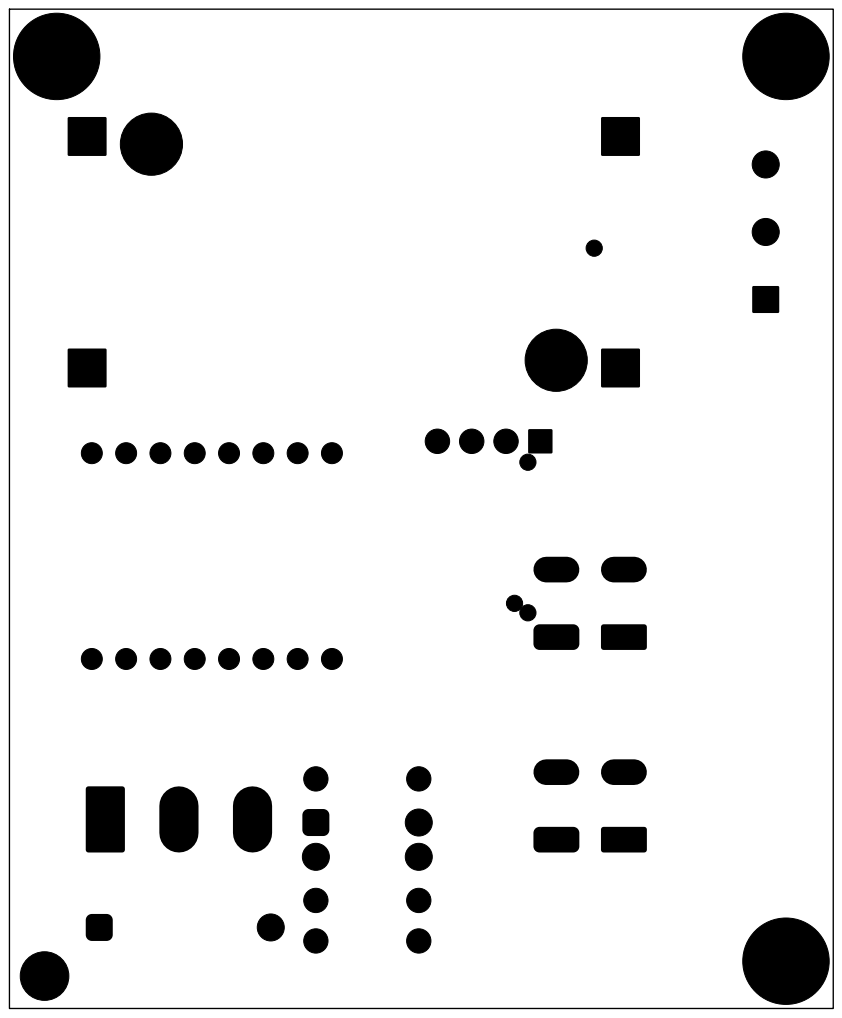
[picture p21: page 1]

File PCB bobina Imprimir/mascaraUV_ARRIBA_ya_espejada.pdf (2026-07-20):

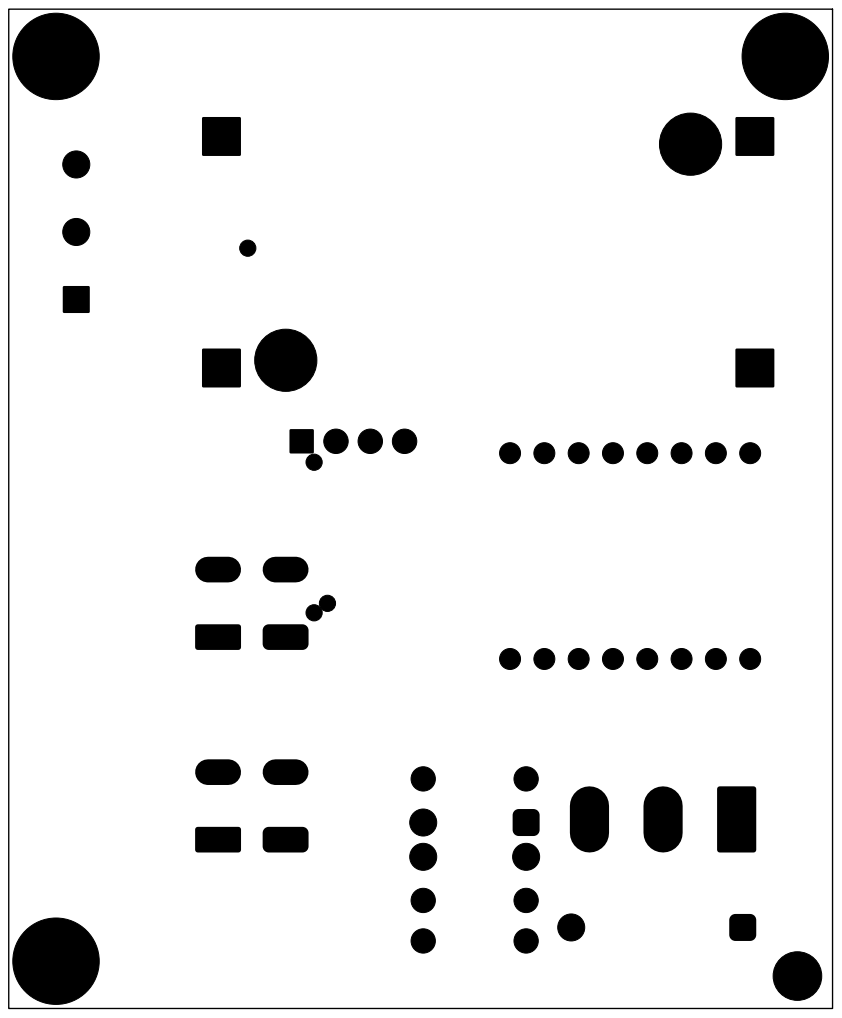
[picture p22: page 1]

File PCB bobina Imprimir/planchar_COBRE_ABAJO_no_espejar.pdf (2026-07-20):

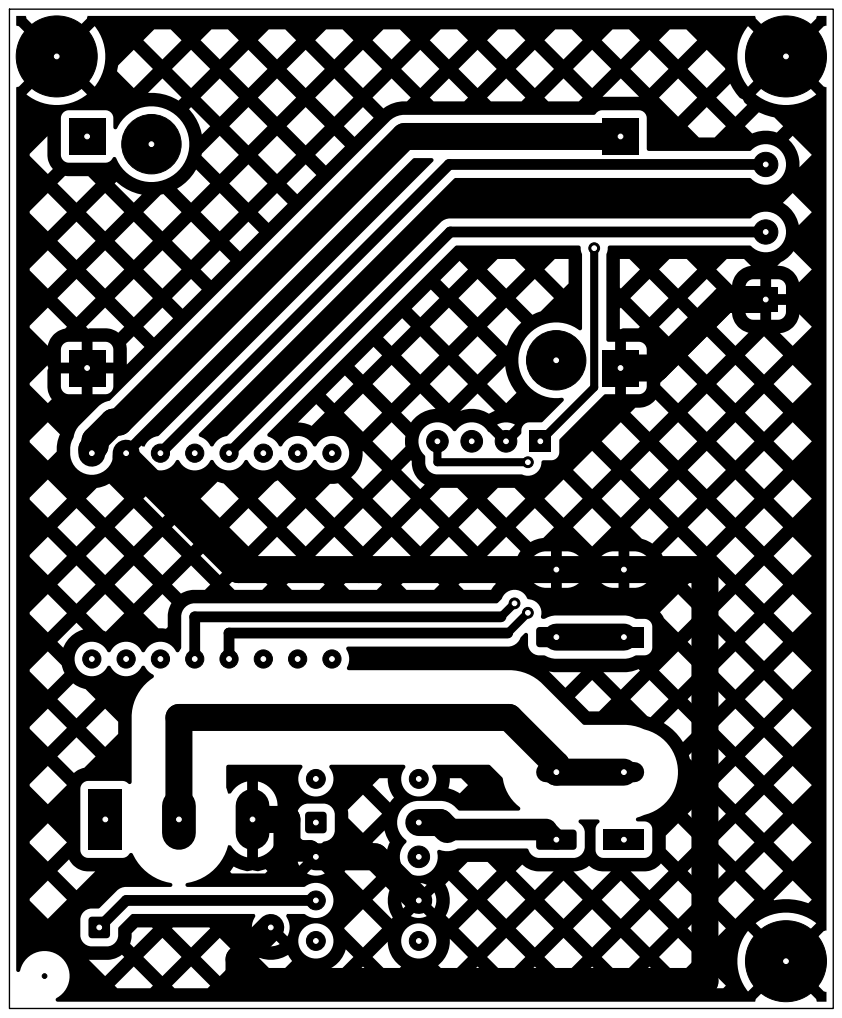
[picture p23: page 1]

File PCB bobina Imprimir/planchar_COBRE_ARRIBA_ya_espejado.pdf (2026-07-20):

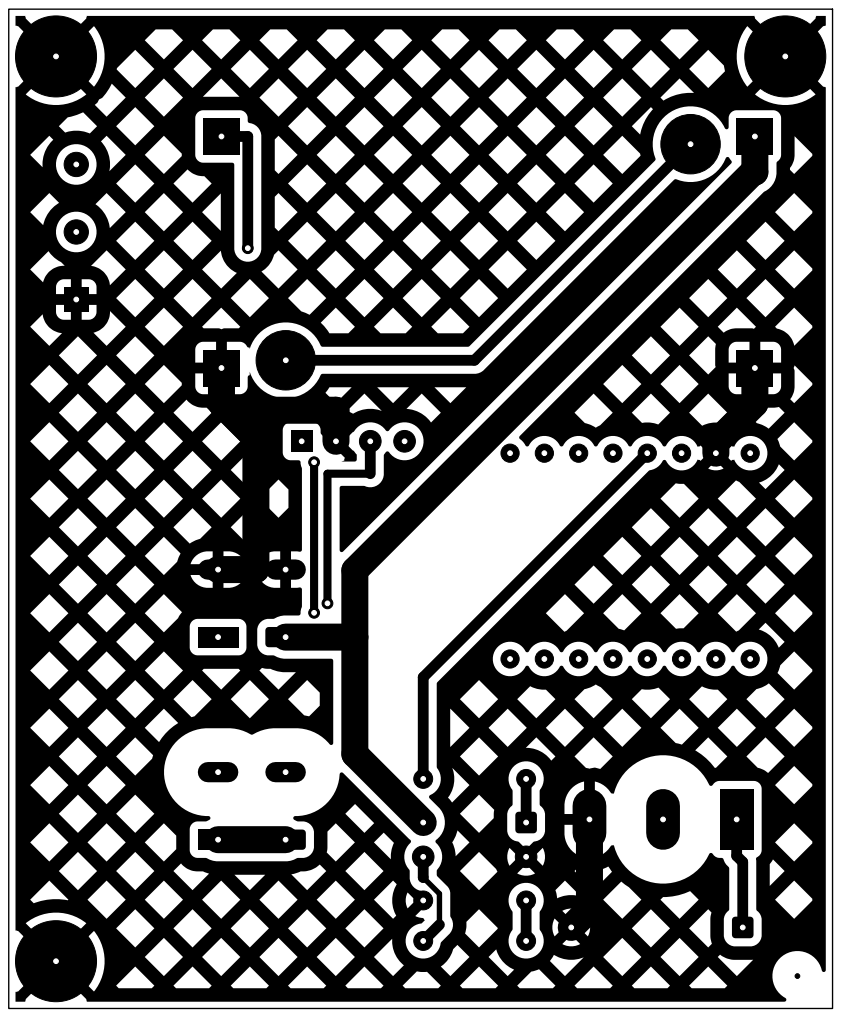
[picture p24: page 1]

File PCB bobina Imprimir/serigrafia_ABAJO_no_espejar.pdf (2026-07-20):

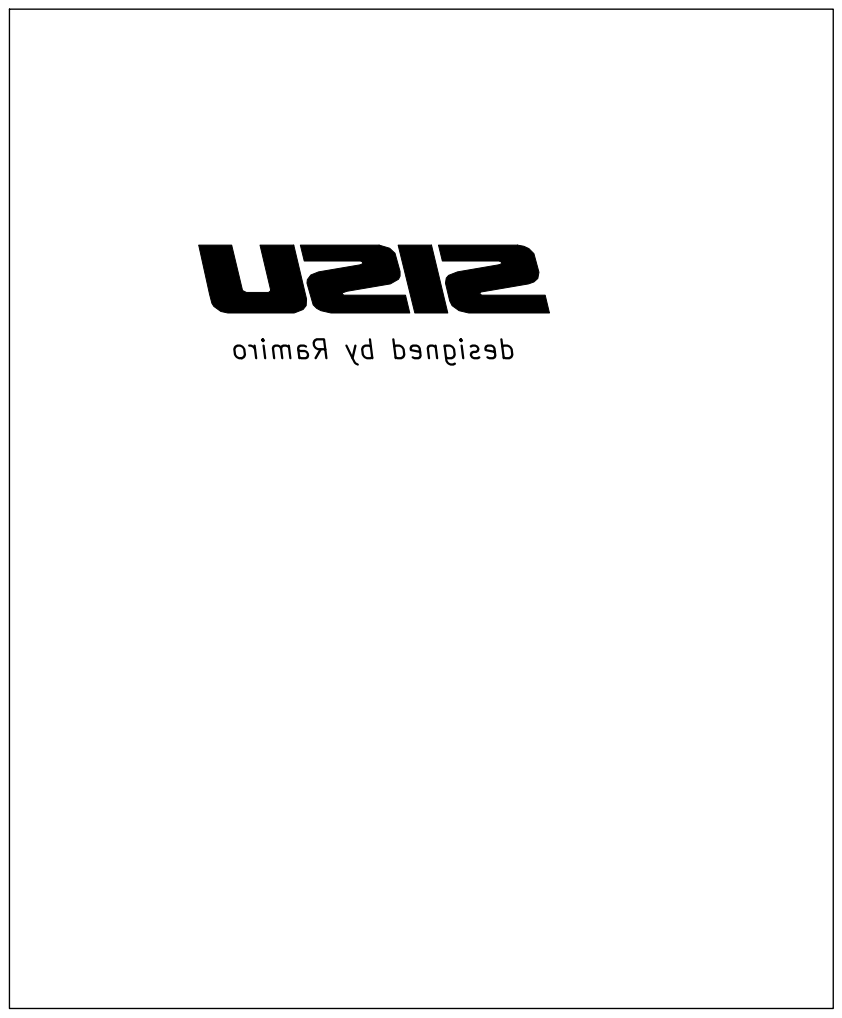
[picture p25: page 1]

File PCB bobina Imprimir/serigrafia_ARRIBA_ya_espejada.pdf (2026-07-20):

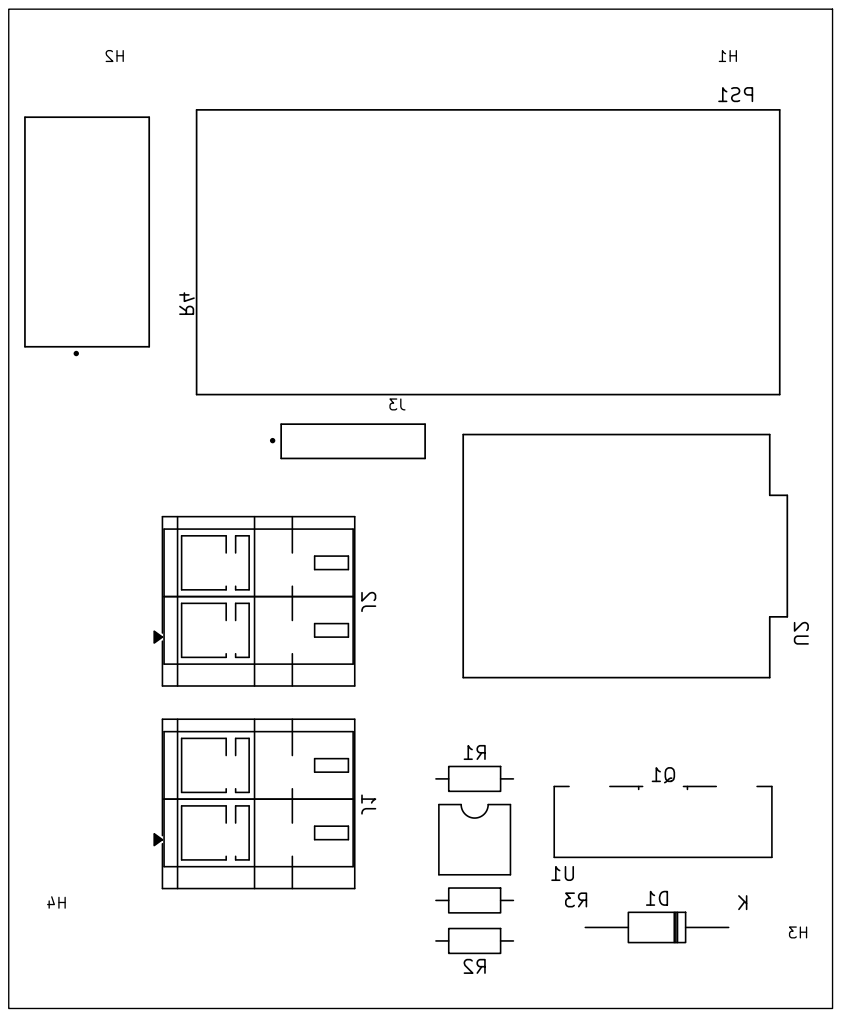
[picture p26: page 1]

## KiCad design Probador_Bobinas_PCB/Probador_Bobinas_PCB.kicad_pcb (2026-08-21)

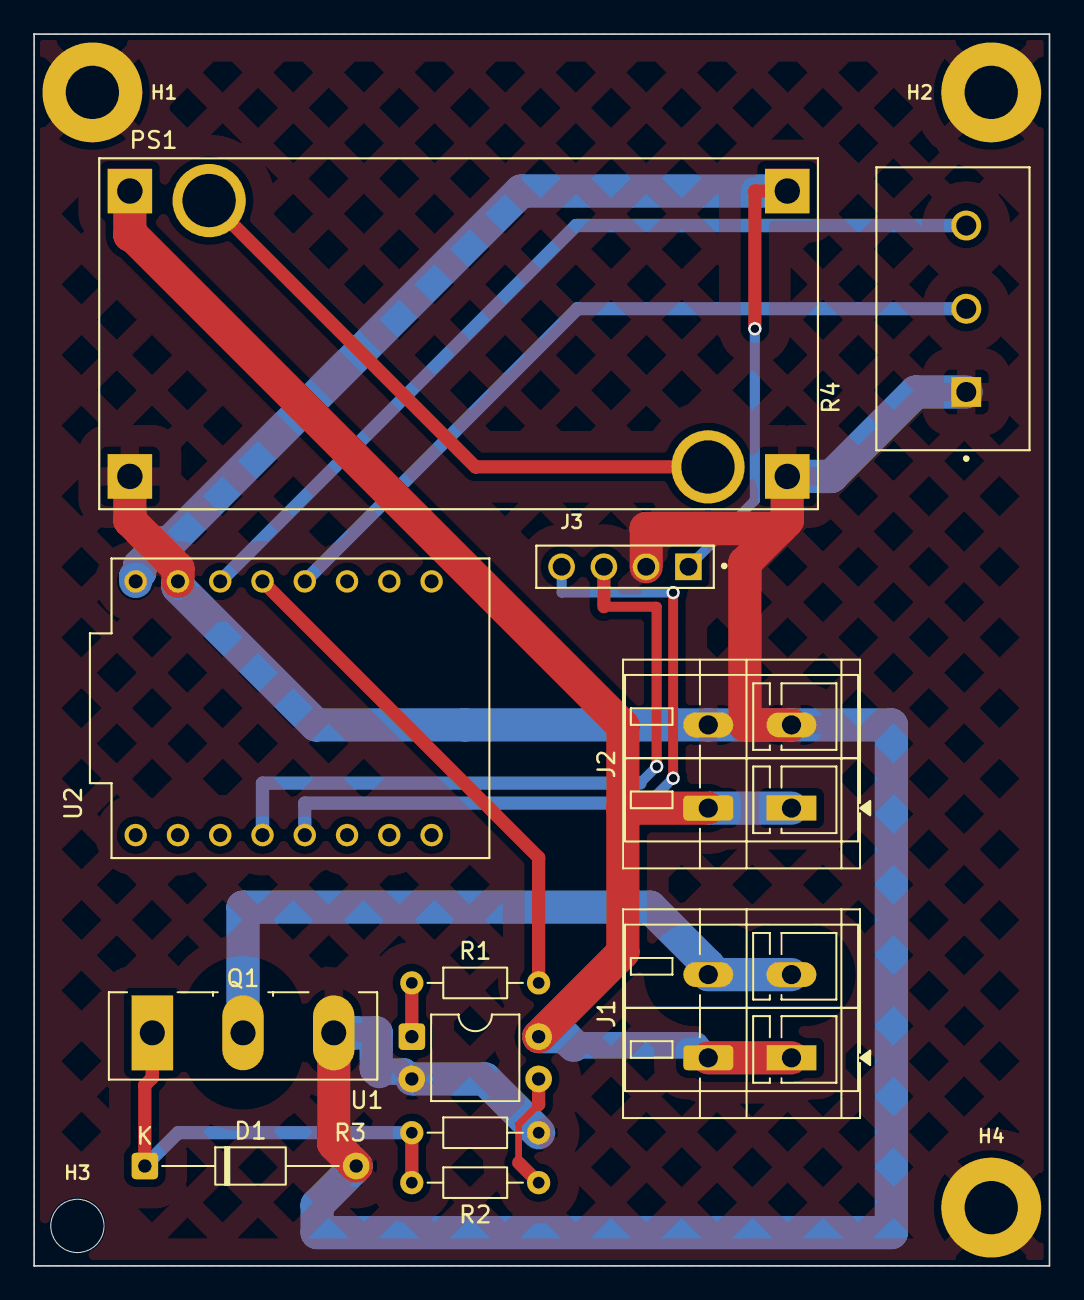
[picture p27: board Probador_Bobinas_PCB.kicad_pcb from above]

Board: 2 copper layers, 61.0 x 74.0 mm, 16 parts (0 on the bottom side), 13 nets.

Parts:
D1: D_Zener 15V; D_DO-35_SOD27_P12.70mm_Horizontal
H1, H2, H3, H4: M3; MountingHole_M3
J1, J2: WAGO_236-402; TerminalBlock_WAGO_236-402_1x02_P5.00mm_45Degree
J3: PPTC041LFBN-RC; SULLINS_PPTC041LFBN-RC
PS1: MC00100; CONV_MC00100
Q1: FGH60N60SFD; TO-247-3_Vertical
R1: R_150; R_Axial_DIN0204_L3.6mm_D1.6mm_P7.62mm_Horizontal
R2: R_100; R_Axial_DIN0204_L3.6mm_D1.6mm_P7.62mm_Horizontal
R3: R_560; R_Axial_DIN0204_L3.6mm_D1.6mm_P7.62mm_Horizontal
R4: WH148-1A-2-18T-L20; TRIM_WH148-1A-2-18T-L20
U1: PC817; DIP-4_W7.62mm
U2: ESP32-C3_SUPERMINI_TH; MODULE_ESP32-C3_SUPERMINI_TH

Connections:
Earth: D1.2 (A), H1.1, H2.1, H4.1, J2.2, J3.2, PS1.IN-, PS1.OUT-, Q1.3 (E), R3.2, R4.1, U1.2, U2.G (GND)
unnamed: D1.1 (K), Q1.1 (G), R2.1, R3.1
unnamed: J1.2, Q1.2 (C)
unnamed: J3.1, PS1.OUT+, U2.5V
unnamed: PS1.MH1 (MOUTING), PS1.MH2 (MOUTING)
unnamed: R1.1, U1.1
unnamed: R2.2, U1.3
unnamed: R4.3, U2.3.3 (3V3)
unnamed: R4.2, U2.3 (GPIO3)
unnamed: R1.2, U2.4 (GPIO4)
unnamed: J3.3, U2.8 (GPIO8)
unnamed: J3.4, U2.9 (GPIO9)
VCC: J1.1, J2.1, PS1.IN+, U1.4

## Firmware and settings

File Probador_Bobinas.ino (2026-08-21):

/*
 * Probador de encendido COP con Pantalla OLED 128x64 (Diseño Mejorado)
 * ESP32-C3 Super Mini + PC817 + IGBT FGH60N60SFD
 */

#include <Wire.h>
#include <Adafruit_GFX.h>
#include <Adafruit_SSD1306.h>

// ---------- Configuración de la Pantalla OLED ----------
#define SCREEN_WIDTH 128
#define SCREEN_HEIGHT 64
#define OLED_RESET    -1
#define SCREEN_ADDRESS 0x3C 

Adafruit_SSD1306 display(SCREEN_WIDTH, SCREEN_HEIGHT, &Wire, OLED_RESET);

// ---------- Bitmap del Logo SISU (128x64px) ----------
const unsigned char epd_bitmap_Logo_SISU [] PROGMEM = {
	0x00, 0x00, 0x00, 0x00, 0x00, 0x00, 0x00, 0x00, 0x00, 0x00, 0x00, 0x00, 0x00, 0x00, 0x00, 0x00, 
	0x00, 0x00, 0x00, 0x00, 0x00, 0x00, 0x00, 0x00, 0x00, 0x00, 0x00, 0x00, 0x00, 0x00, 0x00, 0x00, 
	0x00, 0x00, 0x00, 0x00, 0x00, 0x00, 0x00, 0x00, 0x00, 0x00, 0x00, 0x00, 0x00, 0x00, 0x00, 0x00, 
	0x00, 0x00, 0x00, 0x00, 0x00, 0x00, 0x00, 0x00, 0x00, 0x00, 0x00, 0x00, 0x00, 0x00, 0x00, 0x00, 
	0x00, 0x00, 0x00, 0x00, 0x00, 0x00, 0x00, 0x00, 0x00, 0x00, 0x00, 0x00, 0x00, 0x00, 0x00, 0x00, 
	0x00, 0x00, 0x00, 0x00, 0x00, 0x00, 0x00, 0x00, 0x00, 0x00, 0x00, 0x00, 0x00, 0x00, 0x00, 0x00, 
	0x00, 0x00, 0x00, 0x00, 0x00, 0x00, 0x00, 0x00, 0x00, 0x00, 0x00, 0x00, 0x00, 0x00, 0x00, 0x00, 
	0x00, 0x00, 0x00, 0x00, 0x00, 0x00, 0x00, 0x00, 0x00, 0x00, 0x00, 0x00, 0x00, 0x00, 0x00, 0x00, 
	0x00, 0x00, 0x00, 0x00, 0x00, 0x00, 0x00, 0x00, 0x00, 0x00, 0x00, 0x00, 0x00, 0x00, 0x00, 0x00, 
	0x00, 0x00, 0x00, 0x00, 0x00, 0x00, 0x00, 0x00, 0x00, 0x00, 0x00, 0x00, 0x00, 0x00, 0x00, 0x00, 
	0x00, 0x00, 0x00, 0x00, 0x00, 0x00, 0x00, 0x00, 0x00, 0x00, 0x00, 0x00, 0x00, 0x00, 0x00, 0x00, 
	0x00, 0x00, 0x00, 0x00, 0x00, 0x00, 0x00, 0x00, 0x00, 0x00, 0x00, 0x00, 0x00, 0x00, 0x00, 0x00, 
	0x00, 0x00, 0x00, 0x00, 0x00, 0x00, 0x00, 0x00, 0x00, 0x00, 0x00, 0x00, 0x00, 0x00, 0x00, 0x00, 
	0x00, 0x00, 0x00, 0x00, 0x00, 0x00, 0x00, 0x00, 0x00, 0x00, 0x00, 0x00, 0x00, 0x00, 0x00, 0x00, 
	0x00, 0x00, 0x00, 0x00, 0x00, 0x00, 0x00, 0x00, 0x00, 0x00, 0x00, 0x00, 0x00, 0x00, 0x00, 0x00, 
	0x00, 0x00, 0x00, 0x00, 0x00, 0x00, 0x00, 0x00, 0x00, 0x00, 0x00, 0x00, 0x00, 0x00, 0x00, 0x00, 
	0x00, 0x00, 0x00, 0x00, 0x00, 0x00, 0x00, 0x00, 0x00, 0x00, 0x00, 0x00, 0x00, 0x00, 0x00, 0x00, 
	0x00, 0x00, 0x00, 0x00, 0x00, 0x00, 0x00, 0x00, 0x00, 0x00, 0x00, 0x00, 0x00, 0x00, 0x00, 0x00, 
	0x00, 0x00, 0x00, 0x00, 0x00, 0x00, 0x00, 0x00, 0x00, 0x00, 0x00, 0x00, 0x00, 0x00, 0x00, 0x00, 
	0x00, 0x00, 0x00, 0x00, 0x00, 0x00, 0x00, 0x00, 0x00, 0x00, 0x00, 0x00, 0x00, 0x00, 0x00, 0x00, 
	0x00, 0x00, 0x00, 0x00, 0x00, 0x00, 0x00, 0x00, 0x00, 0x00, 0x00, 0x00, 0x00, 0x00, 0x00, 0x00, 
	0x00, 0x00, 0x00, 0x00, 0x00, 0x00, 0x00, 0x00, 0x00, 0x00, 0x00, 0x00, 0x00, 0x00, 0x00, 0x00, 
	0x00, 0x00, 0x00, 0x00, 0x00, 0x00, 0x00, 0x00, 0x00, 0x00, 0x00, 0x00, 0x00, 0x00, 0x00, 0x00, 
	0x00, 0x00, 0x00, 0x00, 0x00, 0x00, 0x00, 0x00, 0x00, 0x00, 0x00, 0x00, 0x00, 0x00, 0x00, 0x00, 
	0x00, 0x00, 0x00, 0x00, 0x00, 0x00, 0x00, 0x00, 0x00, 0x00, 0x00, 0x00, 0x00, 0x00, 0x00, 0x00, 
	0x00, 0x00, 0x00, 0x03, 0xff, 0xff, 0xdf, 0xef, 0xff, 0xff, 0x7f, 0x03, 0xf8, 0x00, 0x00, 0x00, 
	0x00, 0x00, 0x00, 0x07, 0xff, 0xff, 0xdf, 0xdf, 0xff, 0xfe, 0x7f, 0x03, 0xf8, 0x00, 0x00, 0x00, 
	0x00, 0x00, 0x00, 0x07, 0xf8, 0x00, 0x1f, 0xdf, 0xe0, 0x00, 0xff, 0x03, 0xf8, 0x00, 0x00, 0x00, 
	0x00, 0x00, 0x00, 0x07, 0xff, 0xe0, 0x3f, 0xdf, 0xff, 0x80, 0xfe, 0x07, 0xf8, 0x00, 0x00, 0x00, 
	0x00, 0x00, 0x00, 0x07, 0xff, 0xff, 0x3f, 0x9f, 0xff, 0xfc, 0xfe, 0x07, 0xf0, 0x00, 0x00, 0x00, 
	0x00, 0x00, 0x00, 0x03, 0xff, 0xff, 0xbf, 0x8f, 0xff, 0xfd, 0xfe, 0x07, 0xf0, 0x00, 0x00, 0x00, 
	0x00, 0x00, 0x00, 0x00, 0x0f, 0xff, 0x7f, 0x80, 0x3f, 0xfd, 0xfc, 0x0f, 0xf0, 0x00, 0x00, 0x00, 
	0x00, 0x00, 0x00, 0x00, 0x00, 0xff, 0x7f, 0x00, 0x03, 0xfd, 0xff, 0xff, 0xe0, 0x00, 0x00, 0x00, 
	0x00, 0x00, 0x00, 0x1f, 0xff, 0xff, 0x7f, 0x7f, 0xff, 0xf9, 0xff, 0xff, 0xe0, 0x00, 0x00, 0x00, 
	0x00, 0x00, 0x00, 0x1f, 0xff, 0xfe, 0x7f, 0x7f, 0xff, 0xf9, 0xff, 0xff, 0xc0, 0x00, 0x00, 0x00, 
	0x00, 0x00, 0x00, 0x00, 0x00, 0x00, 0x00, 0x00, 0x00, 0x00, 0x00, 0x00, 0x00, 0x00, 0x00, 0x00, 
	0x00, 0x00, 0x00, 0x00, 0x00, 0x00, 0x00, 0x00, 0x00, 0x00, 0x00, 0x00, 0x00, 0x00, 0x00, 0x00, 
	0x00, 0x00, 0x00, 0x00, 0x00, 0x00, 0x00, 0x00, 0x00, 0x00, 0x00, 0x00, 0x00, 0x00, 0x00, 0x00, 
	0x00, 0x00, 0x00, 0x00, 0x00, 0x00, 0x00, 0x00, 0x00, 0x00, 0x00, 0x00, 0x00, 0x00, 0x00, 0x00, 
	0x00, 0x00, 0x00, 0x00, 0x00, 0x00, 0x00, 0x00, 0x00, 0x00, 0x00, 0x00, 0x00, 0x00, 0x00, 0x00, 
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
};

// ---------- Pines y Constantes del Sistema ----------
const int   PIN_POT   = 3;     
const int   PIN_PWM   = 4;     
const int   PIN_SDA   = 8;     
const int   PIN_SCL   = 9;     

const int   FREQ_MIN  = 10;    
const int   FREQ_MAX  = 200;   
const float DWELL_MS  = 3.0;   
const float DUTY_MAX  = 0.40;  

const int   RES_BITS  = 14;
const uint32_t DUTY_FULL = (1UL << RES_BITS) - 1;

#if !defined(ESP_ARDUINO_VERSION_MAJOR) || ESP_ARDUINO_VERSION_MAJOR < 3
  #define CORE_V2              
  const int PWM_CHANNEL = 0;
#endif

int      freqActual = 0;
uint32_t lastOled = 0;
bool     hayOled = false;

uint32_t freqReal() {
#ifdef CORE_V2
  return ledcReadFreq(PWM_CHANNEL);
#else
  return ledcReadFreq(PIN_PWM);
#endif
}

bool aplicarPwm(int freq, uint32_t duty) {
#ifdef CORE_V2
  bool ok = ledcChangeFrequency(PWM_CHANNEL, freq, RES_BITS) != 0;
  ledcWrite(PWM_CHANNEL, duty);
#else
  bool ok = ledcChangeFrequency(PIN_PWM, freq, RES_BITS) != 0;
  ledcWrite(PIN_PWM, duty);
#endif
  return ok;
}

uint32_t dutyParaDwell(int freq) {
  float dutyFrac = DWELL_MS * freq / 1000.0f;
  if (dutyFrac > DUTY_MAX) dutyFrac = DUTY_MAX;
  return dutyFrac * DUTY_FULL;
}

void setup() {
  Serial.begin(115200);
  Wire.begin(PIN_SDA, PIN_SCL);

  if(display.begin(SSD1306_SWITCHCAPVCC, SCREEN_ADDRESS)) {
    hayOled = true;
    display.clearDisplay();
    display.drawBitmap(0, 2, epd_bitmap_Logo_SISU, 128, 64, WHITE);
    display.fillRect(0, 55, 128, 9, BLACK); 
    display.display();
    delay(2000);
  }

  analogReadResolution(12);

#ifdef CORE_V2
  ledcSetup(PWM_CHANNEL, FREQ_MIN, RES_BITS);
  ledcAttachPin(PIN_PWM, PWM_CHANNEL);
  bool pwmOk = true;
#else
  bool pwmOk = ledcAttach(PIN_PWM, FREQ_MIN, RES_BITS);
#endif

  if (!pwmOk) {
    while (true) delay(1000);
  }

  freqActual = FREQ_MIN;
  aplicarPwm(FREQ_MIN, dutyParaDwell(FREQ_MIN));
}

void loop() {
  long suma = 0;
  for (int i = 0; i < 16; i++) suma += analogRead(PIN_POT);
  int adc = suma / 16;

  int freq = map(adc, 0, 4095, FREQ_MIN, FREQ_MAX);

  if (abs(freq - freqActual) >= 2) {
    freqActual = freq;
    aplicarPwm(freqActual, dutyParaDwell(freqActual));
  }

  if (millis() - lastOled >= 200) {
    lastOled = millis();
    int rpm = freqActual * 30; 
    int dutyPct = int(100.0f * dutyParaDwell(freqActual) / DUTY_FULL);

    if (hayOled) {
      display.clearDisplay();
      
      // 1. Encabezado limpio y compacto (Tamaño 1)
      display.setTextSize(1);
      display.setTextColor(WHITE);
      display.setCursor(0, 0);
      display.print(F("PROBADOR DE BOBINAS"));
      
      // Línea divisoria delgada
      display.drawFastHLine(0, 10, 128, WHITE);

      // 2. RPM destacadas en tamaño grande (Tamaño 2) para verlas fácil
      display.setTextSize(2);
      display.setCursor(0, 15);
      display.print(rpm);
      display.setTextSize(1);
      display.setCursor(82, 21);
      display.print(F("RPM"));

      // 3. Frecuencia y Dwell en la parte inferior con espacio holgado
      display.setCursor(0, 39);
      display.print(F("Freq: "));
      display.print(freqReal());
      display.print(F("Hz"));

      display.setCursor(0, 52);
      display.print(F("Dwell:"));
      display.print(DWELL_MS, 1);
      display.print(F("ms  D:"));
      display.print(dutyPct);
      display.print(F("%"));

      display.display();
    }
  }
}

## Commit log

2026-07-20 Probador de bobinas COP - proyecto completo
    Firmware ESP32-C3 + PCB KiCad (61x74mm, IGBT FGH60N60SFD, LM2596, WH148).
    Incluye gerbers para fabricar, PDFs para fabricacion casera (planchado + mascara UV),
    libreria KiCad con modelos 3D, esquematico PDF y BOM.
    [BOM_lista_de_materiales.csv, ESP32-C3_SUPERMINI_TH.step, LCD_20x4_NHD-0420H1Z.step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]
2026-07-20 Logo SISU + designed by Ramiro en serigrafia inferior
    Logo vectorizado del PNG (canal alfa) a 4 poligonos en B.SilkS, 26mm,
    espejado para leerse desde abajo. Gerbers regenerados y nuevo PDF
    serigrafia_ABAJO para el metodo casero.
    [Probador_Bobinas_PCB.kicad_pcb]
2026-07-20 Actualizacion completa post-logo: README, PDFs, STEP 3D, BOM
    README reescrito: documenta la PCB final (IGBT, LM2596, reglas HV,
    taladros GND), estructura del repo y guia de fabricacion casera/JLCPCB.
    Todas las salidas regeneradas con el estado final de la placa.
    [Probador_Bobinas_3D.step]
2026-07-20 Firmware v2 (IGBT: 200Hz/dwell 3ms) + Documentacion Rev.2 con indice
    - FREQ_MAX 60->200 y DWELL_MS 2->3: limites del MOSFET v1 ya no aplican
    con el FGH60N60SFD; comentarios y cabecera actualizados a la PCB v2.
    - PDF Rev.2: indice con paginas, seccion de firmware, puesta en marcha,
    solucion de problemas, historial v1->v2, seguridad y esquematico anexo.
    - Repo ahora publico.
    [Probador_Bobinas.ino]
2026-07-20 Documentacion Rev.2 final: codigo fuente comentado + QR al repositorio
    Seccion 14 con la estructura del firmware explicada bloque por bloque y
    el listado completo del .ino; codigo QR en la seccion de repositorio.
2026-08-21 Actualiza probador y agrega carcasa imprimible
    [Probador_Bobinas_PCB.kicad_pcb]
2026-08-21 Muestra render de carcasa en README
